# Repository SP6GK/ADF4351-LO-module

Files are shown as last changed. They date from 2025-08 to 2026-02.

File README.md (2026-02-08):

# High Quality RF Local Oscillator Module (ADF4351)

## Overview

This open-source PCB module is designed as a **drop in solution** for any project that requires a **high quality RF continuous wave signal** with at least **16 dBm output power**.  

I present more details on my website: [www.sp6gk.com](https://www.sp6gk.com/).

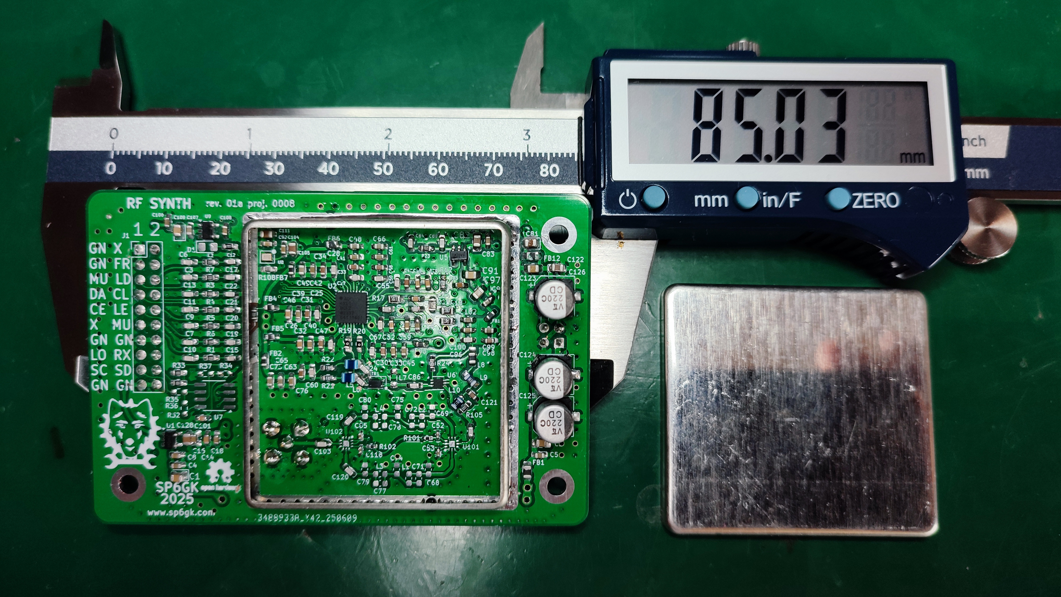
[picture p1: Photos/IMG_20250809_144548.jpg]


The design emphasizes:

- Output power (16–20 dBm depending on frequency)
- Low phase noise
- Minimal harmonics
- Easy integration into custom designs

Originally developed for the **Presto HF to QO-100 transverter project**, this module can be used in a wide variety of RF applications.

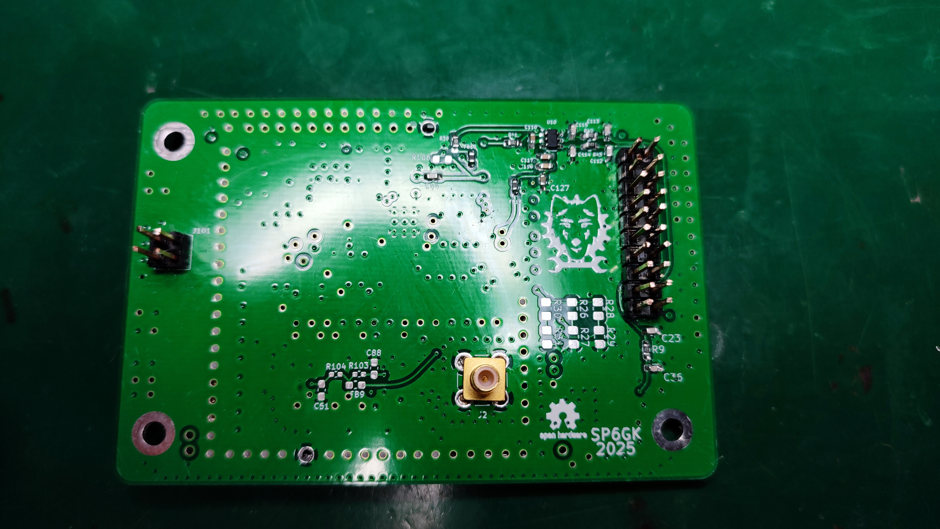
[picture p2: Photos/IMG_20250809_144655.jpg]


---

## Features & Specifications

| Parameter | Value |
|---|---|
| **Optimal Frequency Range** | 400 MHz – 800 MHz (tunable for other ranges) or 1.5-2.1 GHz |
| **Output Power** | 20 dBm (50 Ω load) within optimal range |
| **Power Across Wide Range** | >17 dBm from 100 MHz to 2.4 GHz |
| **Phase Noise @ 400 MHz CW** | -89 dBc/Hz @ 100 Hz offset<br>-97 dBc/Hz @ 10 kHz offset |
| **Reference** | onboard 48 MHz 0.5 ppm VCTCXO + 12-bit DAC digital tuning (or external reference) |
| **Filtering** | Two selectable low-pass filters |
| **PLL Chipset** | Fractional-N PLL (Analog Devices ADF4351) |
| **Dimensions** | 85 × 57 mm |
| **Supply Voltage** | 3.6 V recommended (5.5 V absolute maximum) for logic, 5.3 V for PA stage (5.5 V absolute maximum) |
| **Current Consumption** | < 250 mA (can be reduced by disabling output) |
| **Calibration Storage** | On-board EEPROM |
| **Interface** | SPI (programming PLL) + 3.3 V input pins for switching filters, PA enable etc... |

---

## Applications

- Test and Measurement Equipment
- VHF/UHF Communication Systems
- Amateur Radio
- Backhaul network

---

## Current revisions:
- 400 to 800 MHz rev 01a (tested and presented in the measurements)
- 400 to 800 MHz rev 01b (adds triplexer before amplifier to minimize reflections)
- 1.5-2.1 GHz rev 01a (tuned for higher frequency, includes triplexer and microstrip LPF)

## Performance Measurements

Testing was performed using a **Keysight CXA Spectrum Analyzer (N9000B)** with the **phase noise measurement** option.

**100 MHz**  
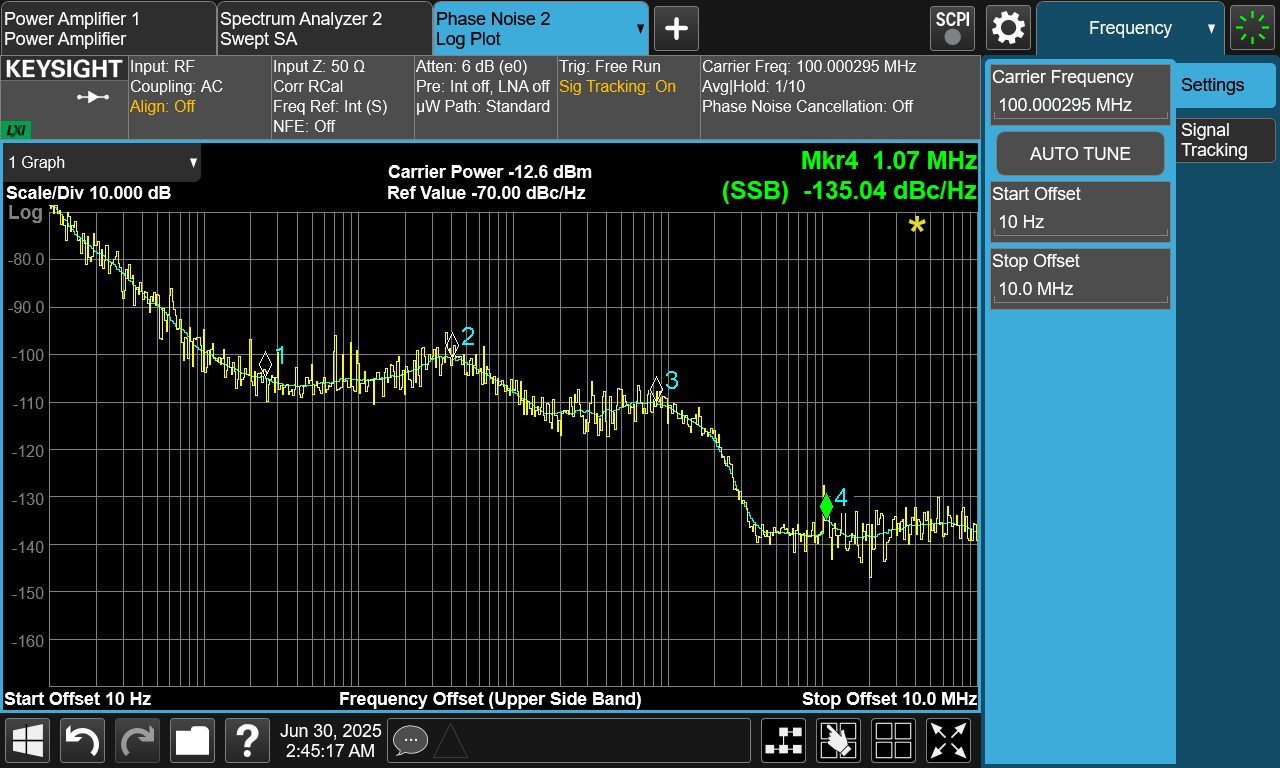
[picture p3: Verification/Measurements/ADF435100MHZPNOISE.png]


**400 MHz**  
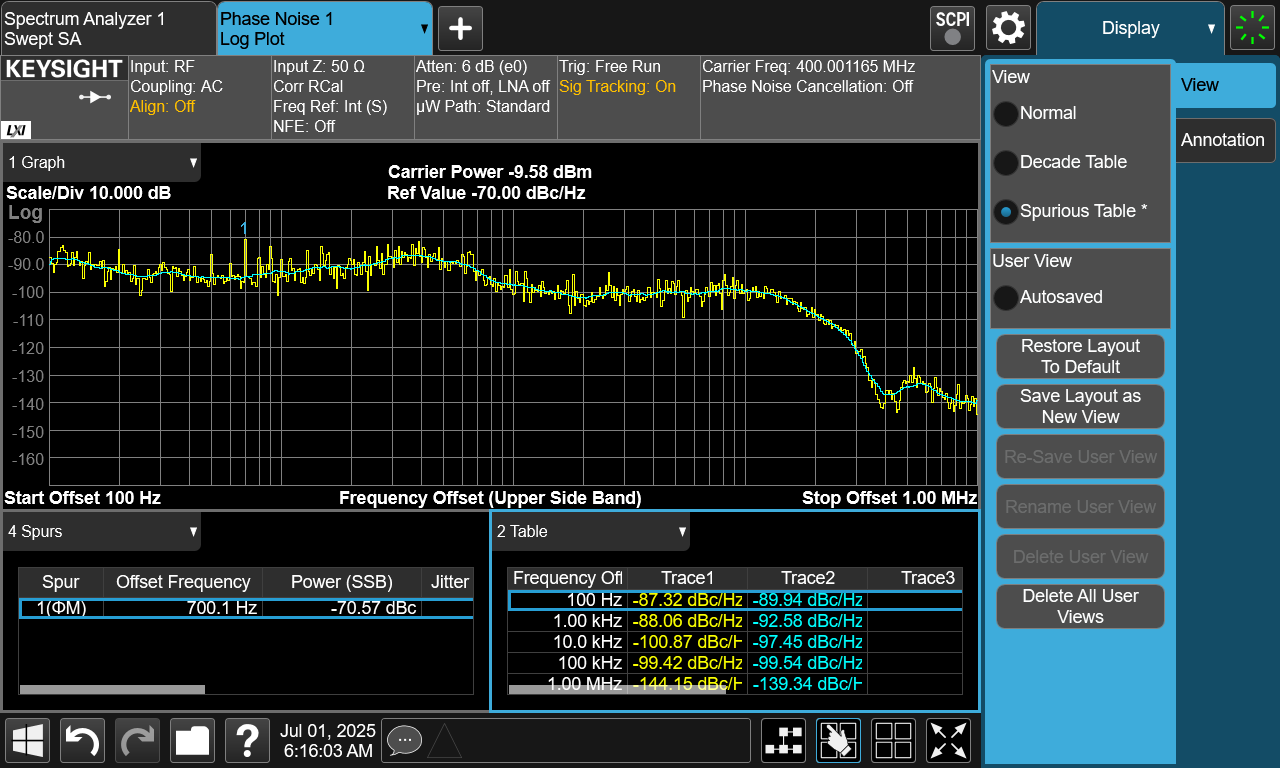
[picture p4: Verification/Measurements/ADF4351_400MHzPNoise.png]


**1.2 GHz**  
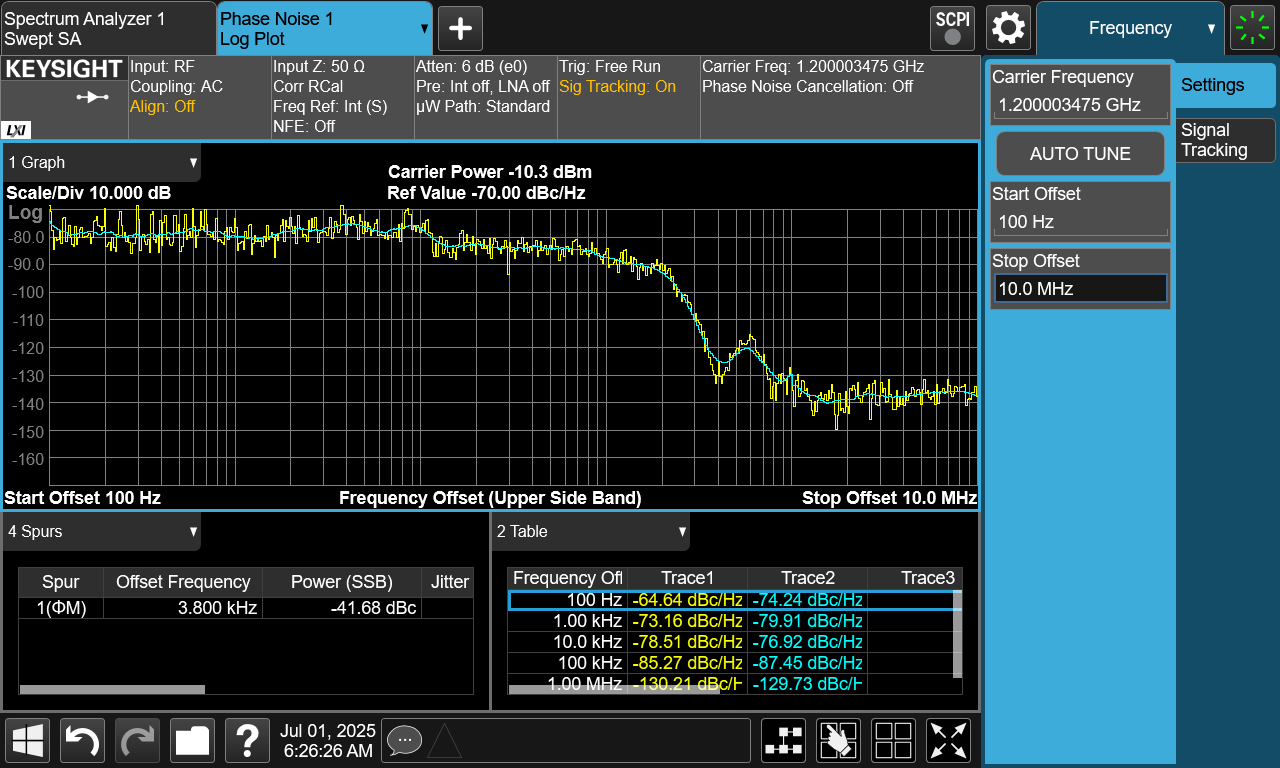
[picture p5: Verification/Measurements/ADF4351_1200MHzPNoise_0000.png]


---

### Harmonics & Output Spectra

**100 MHz CW (50 MHz span)**  
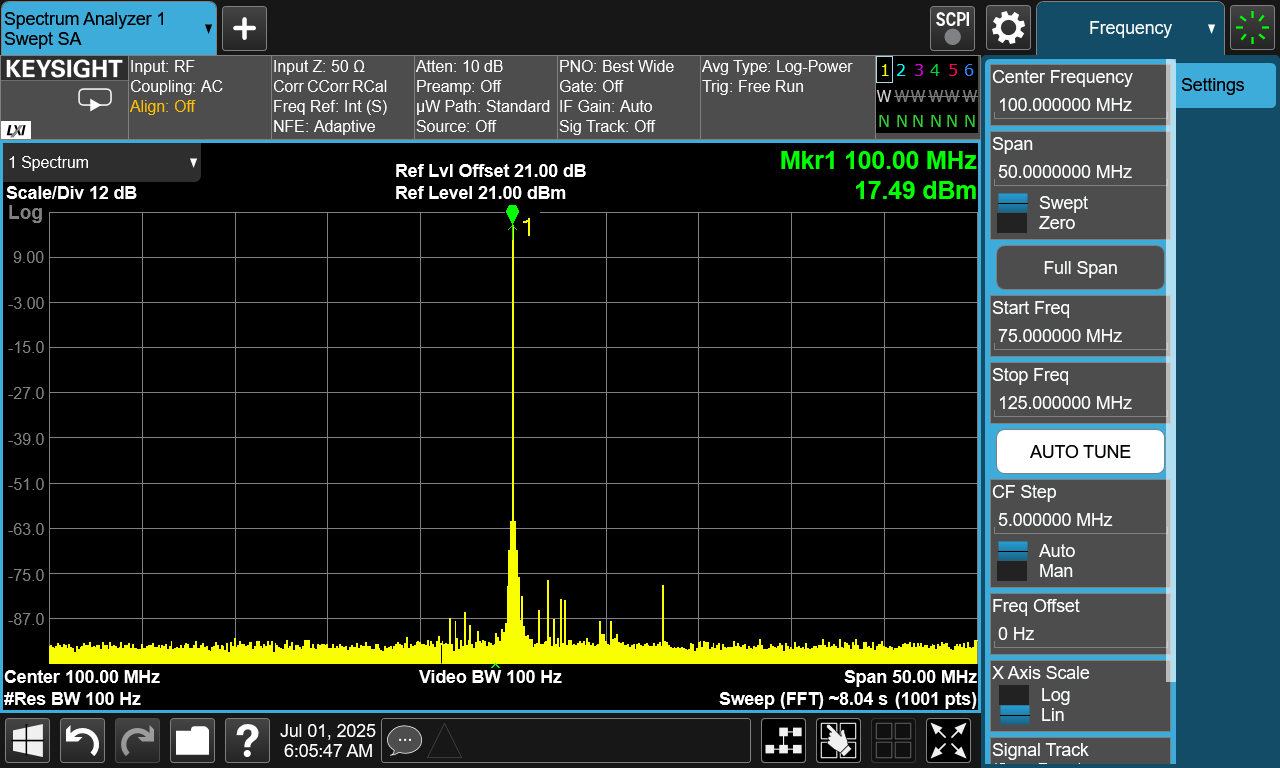
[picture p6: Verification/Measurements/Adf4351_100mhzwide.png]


**400 MHz CW (10 MHz span)**  
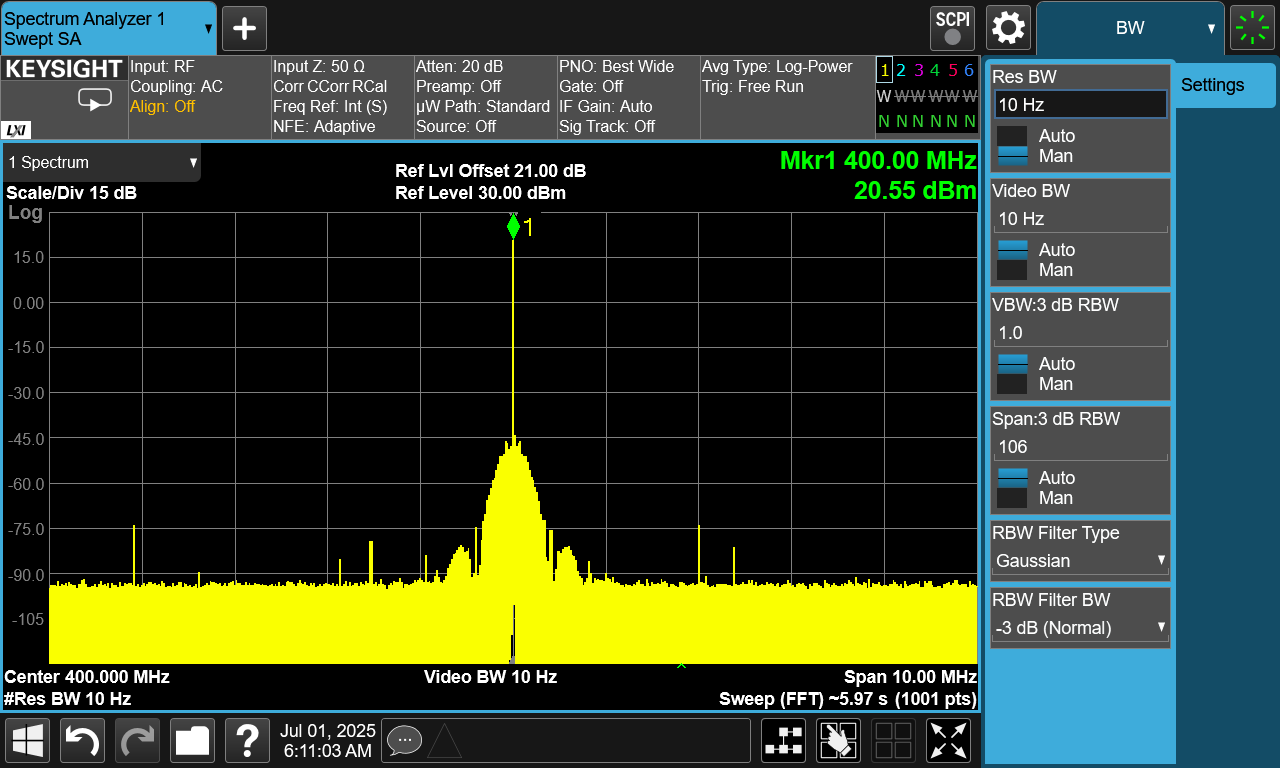
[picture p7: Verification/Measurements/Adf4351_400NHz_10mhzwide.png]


---
Module was tested with STM32F407 discovery board, using driver written by [KB3GTN](https://github.com/kb3gtn/STM32_ADF4351).

---
### What's next?

I intended to use this module for driving a passive RF mixer, however since then I have learned that those work better with square wave LO with lower amplitude.

Currently I am working on revision of this board with LMX2572LP.
I have found this IC to be easier to program while offering better performance especially in terms of spurious emissions.

---

## Repository Contents
- **/ECAD** (Kicad Project, simulations)
- **/Fabrication** (Gerbers)
- **/Verification** (Measurements)
- **/Documents** (BOM)
- **/Photos** (photos of assembled PCB)

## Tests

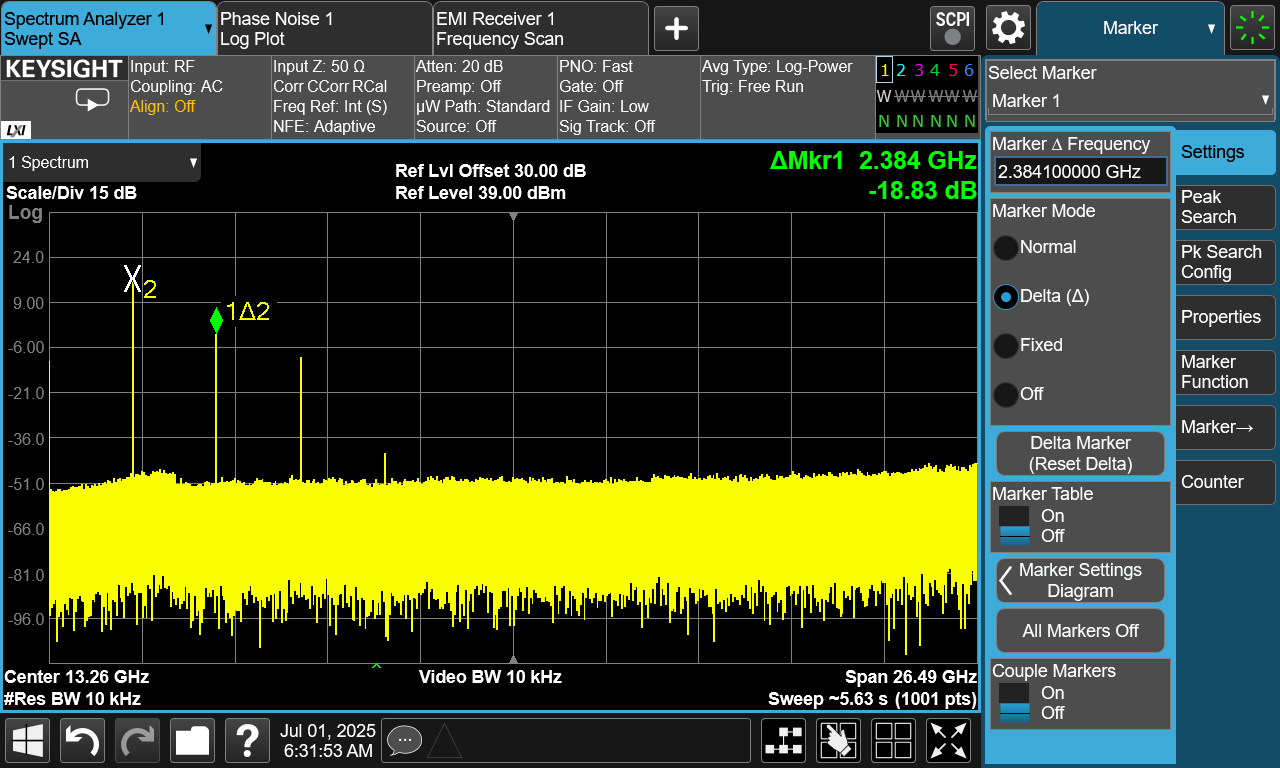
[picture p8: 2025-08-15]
Verification/Measurements/Adf4351_2400MHz_harmonics.png

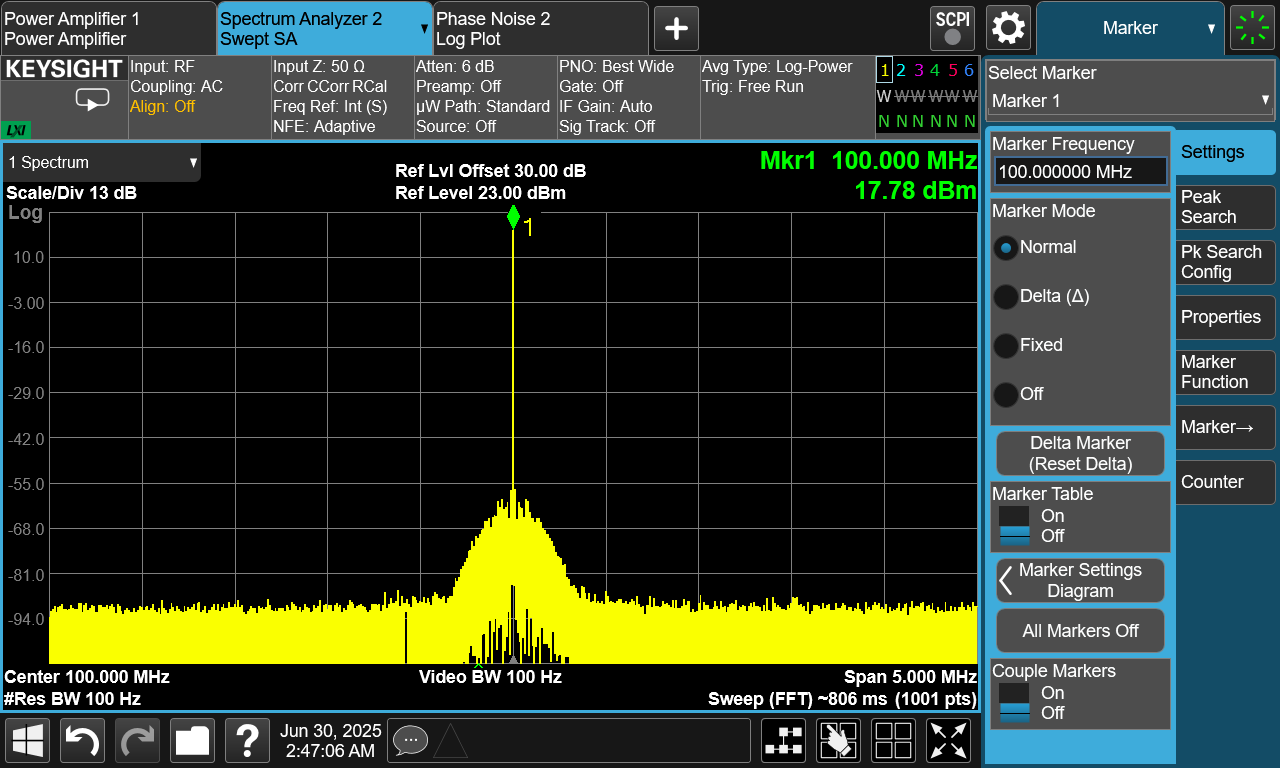
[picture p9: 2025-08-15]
Verification/Measurements/ADF435100MHZPNOISE_0000.png

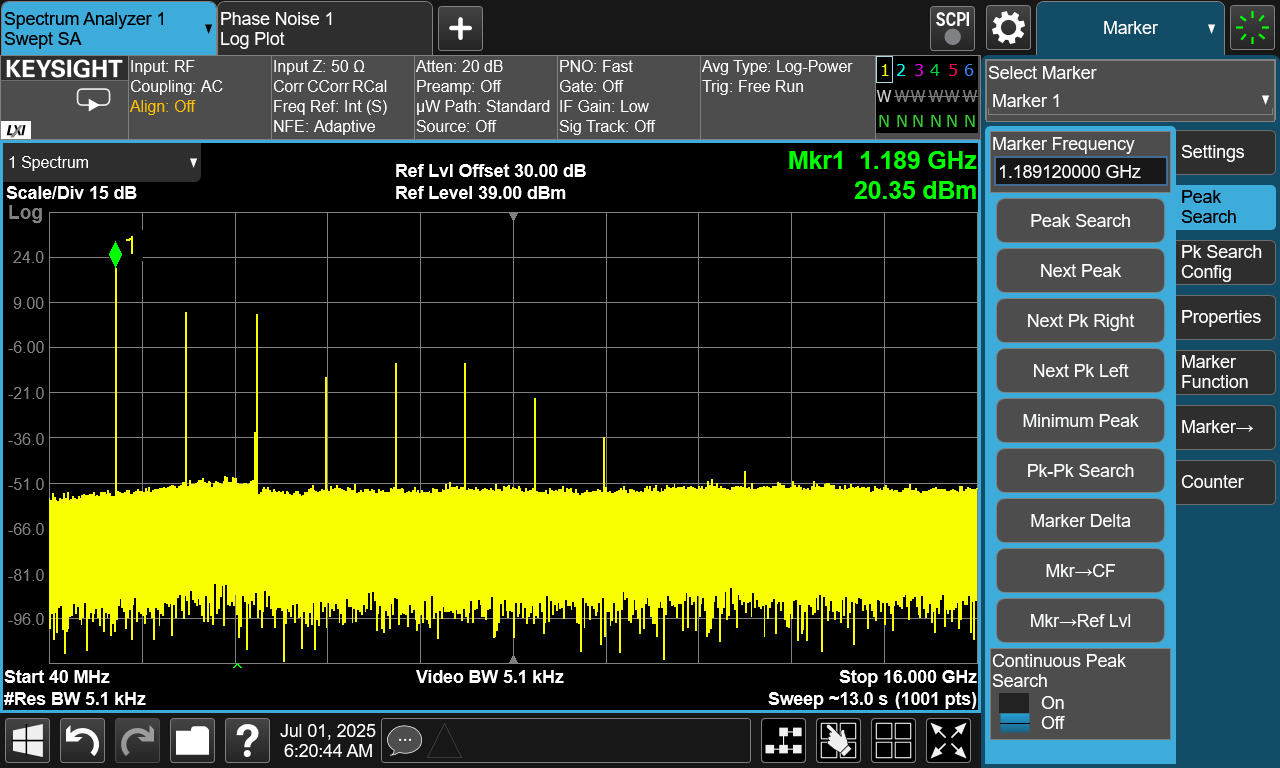
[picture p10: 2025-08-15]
Verification/Measurements/Adf4351_1200MHz_Harmonics_0000.png

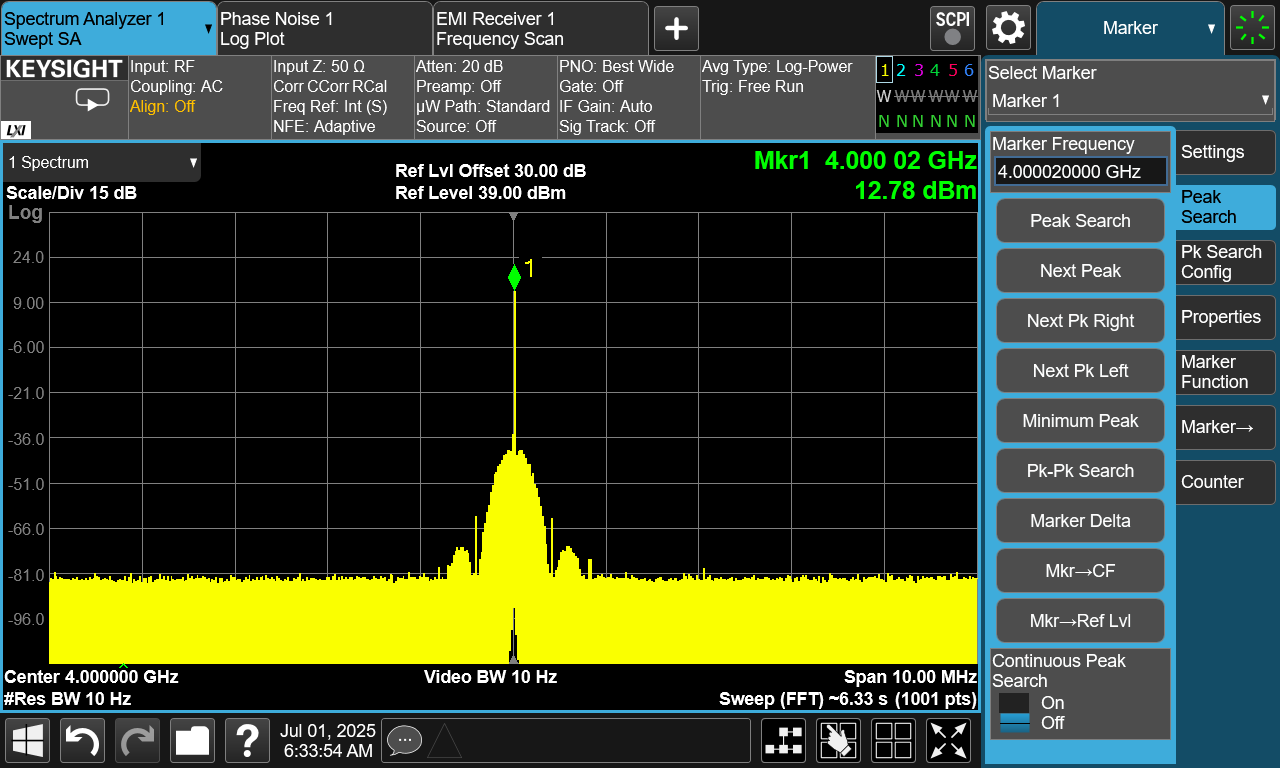
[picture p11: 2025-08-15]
Verification/Measurements/Adf4351_4000MHz_narrow_0000.png

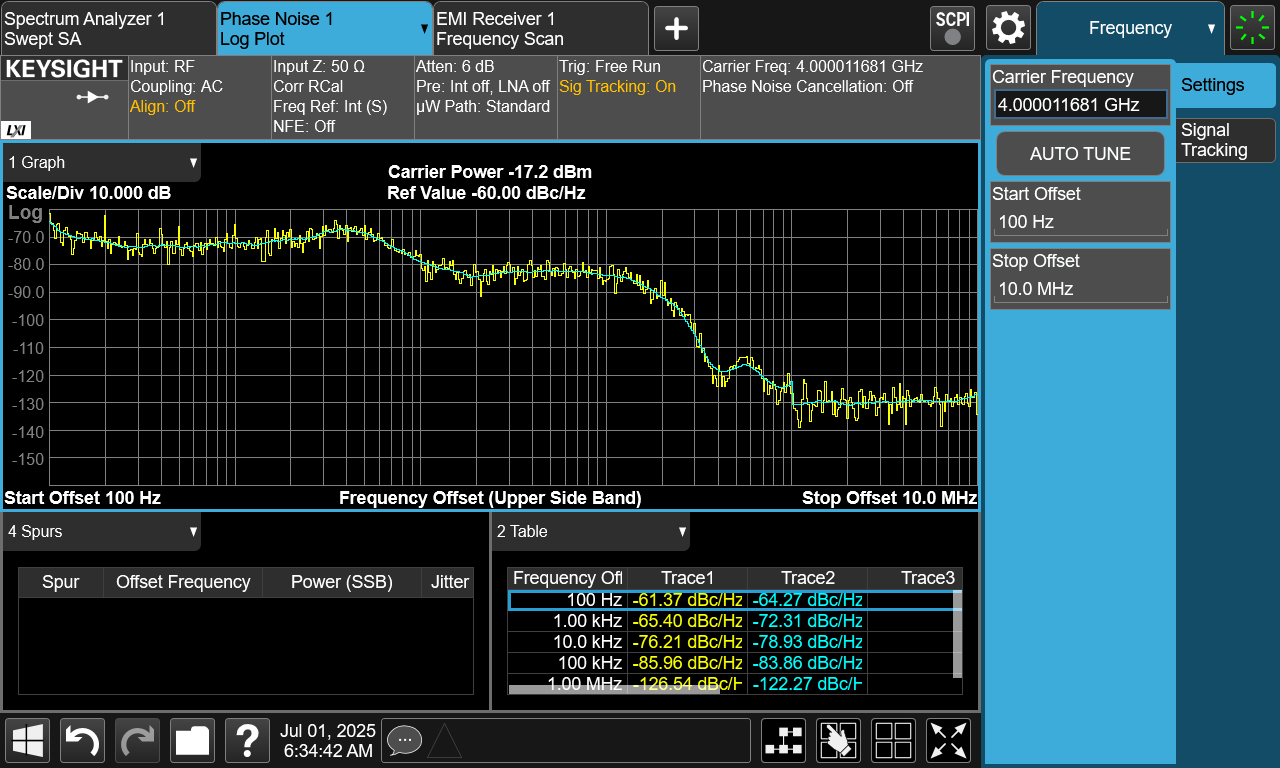
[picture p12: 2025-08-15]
Verification/Measurements/ADF4351_4000MHz_Pnoise.png

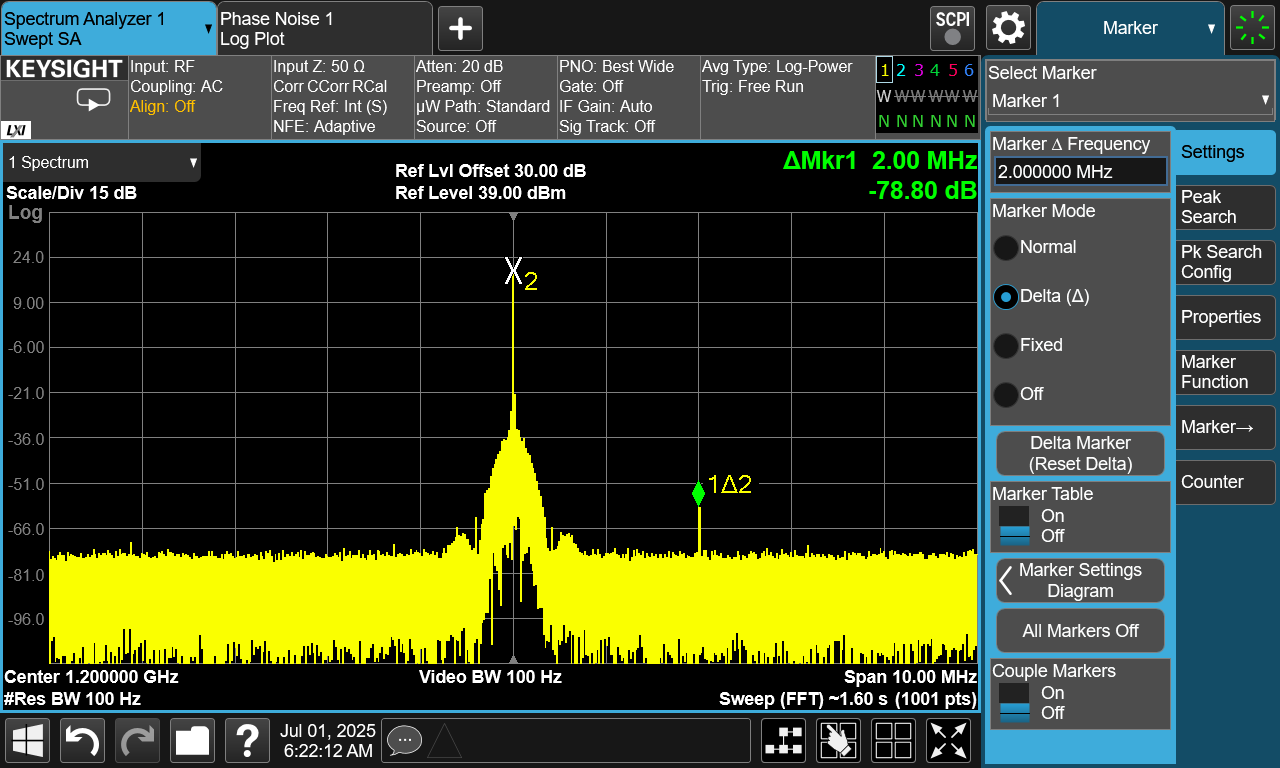
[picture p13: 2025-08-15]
Verification/Measurements/Adf4351_1200MHz_narrow.png

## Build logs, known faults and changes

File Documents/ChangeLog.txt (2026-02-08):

400MHz-800MHz_rev01a initial variant
400MHz-800MHz_rev01b:
    -Added triplexer before amplifier (uses low band)
    -Moved CE resistor to the bottom side so that it is not on the exposed F mask right next to the shield

2GHz_rev01a
    -Adapted to other frequency range:
        -Changed Balun, coupling capacitor, removed two bands and replaced them with one microstrip LPF.
    -Added triplexer before amplifier (uses mid band)
    -Moved CE resistor to the bottom side so that it is not on the exposed F mask right next to the shield

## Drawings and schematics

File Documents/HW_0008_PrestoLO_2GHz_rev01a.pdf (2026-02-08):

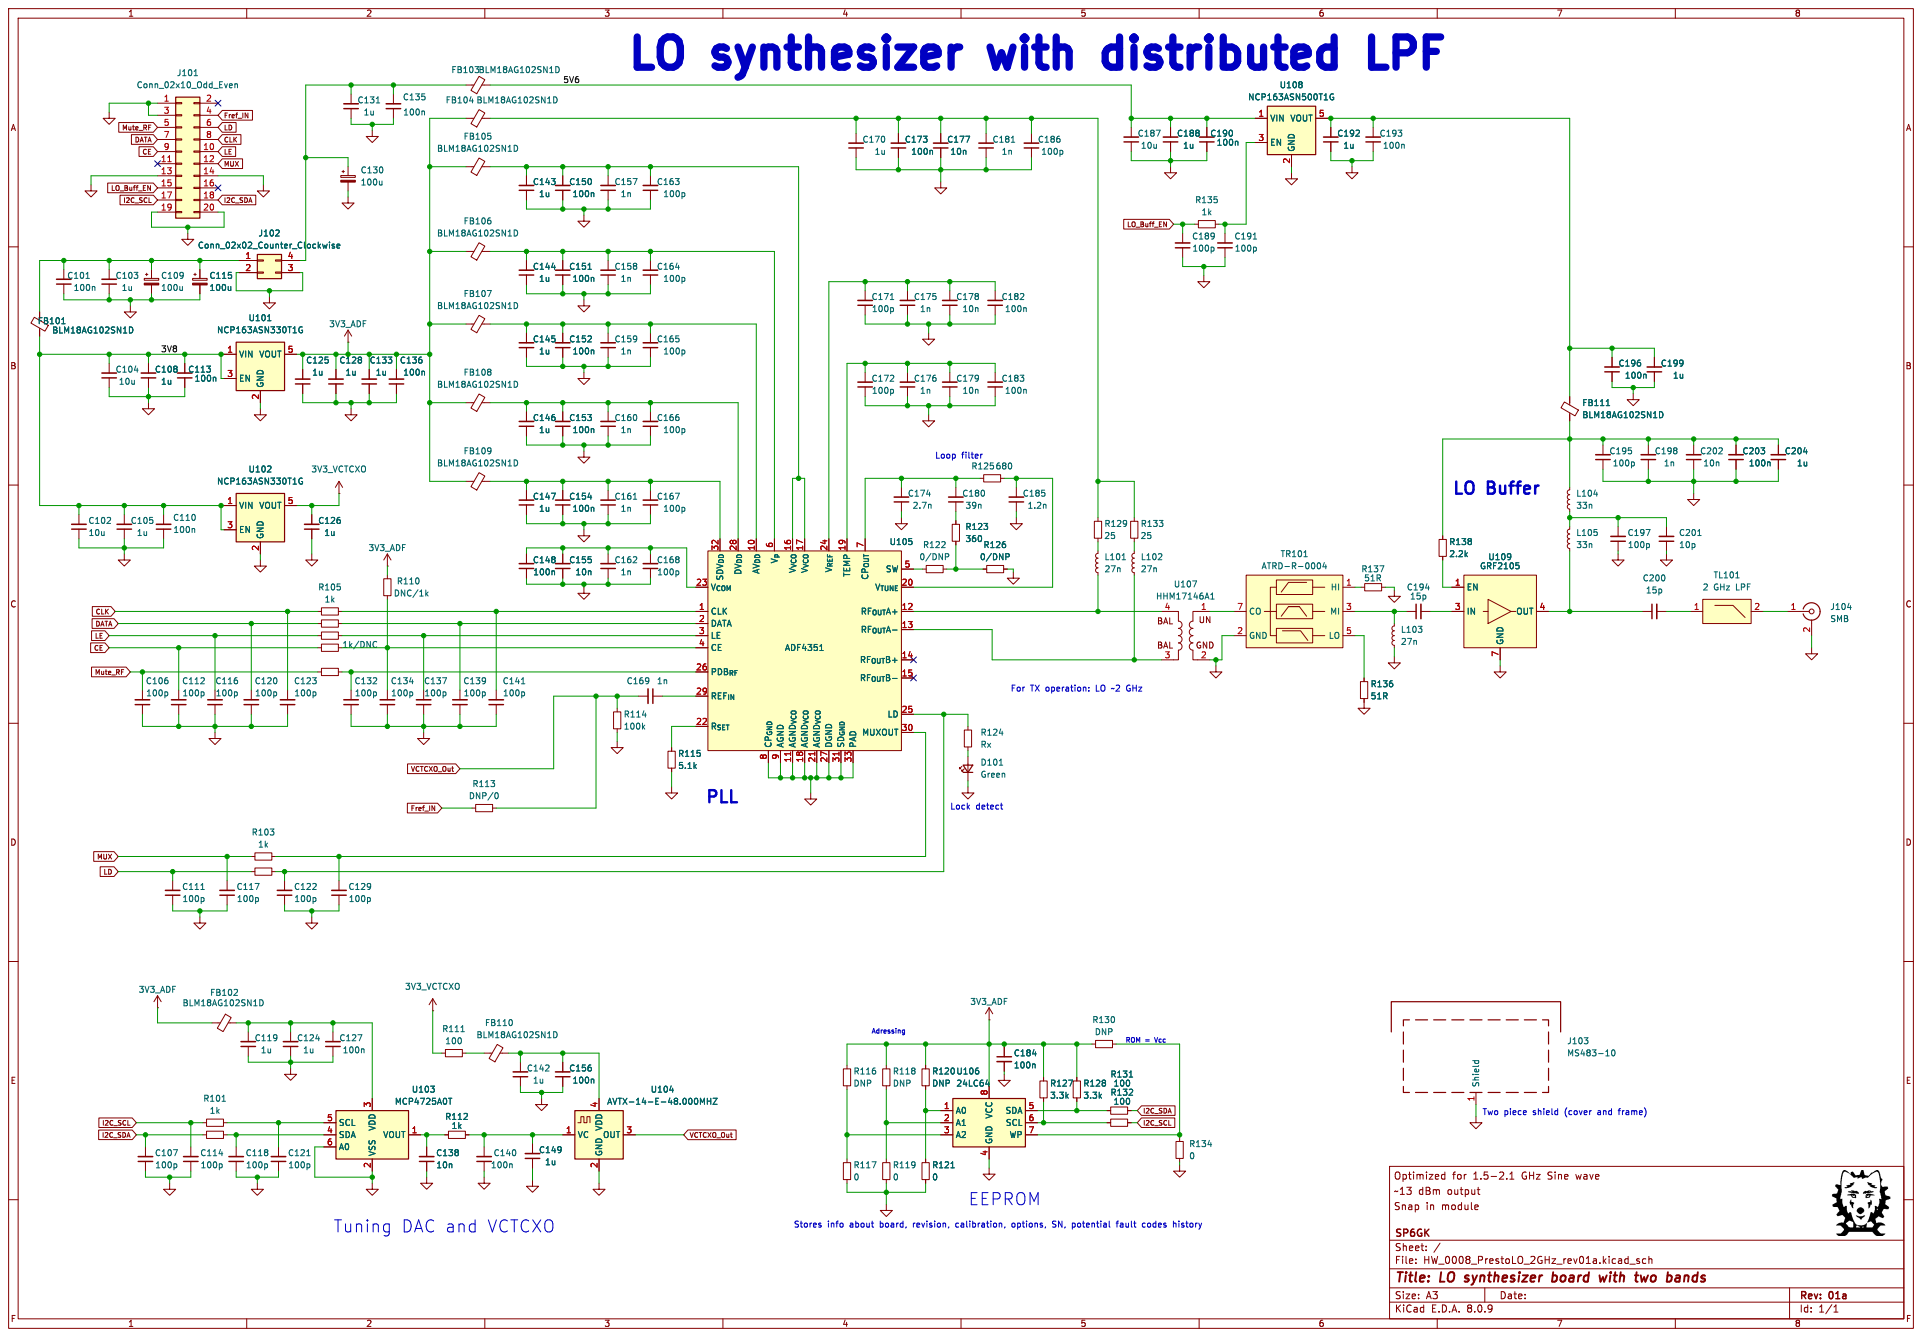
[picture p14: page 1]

4 SDA 5 SCL 6 WP 7 VCC

Id: 1/1 Title: LO synthesizer board with two bands

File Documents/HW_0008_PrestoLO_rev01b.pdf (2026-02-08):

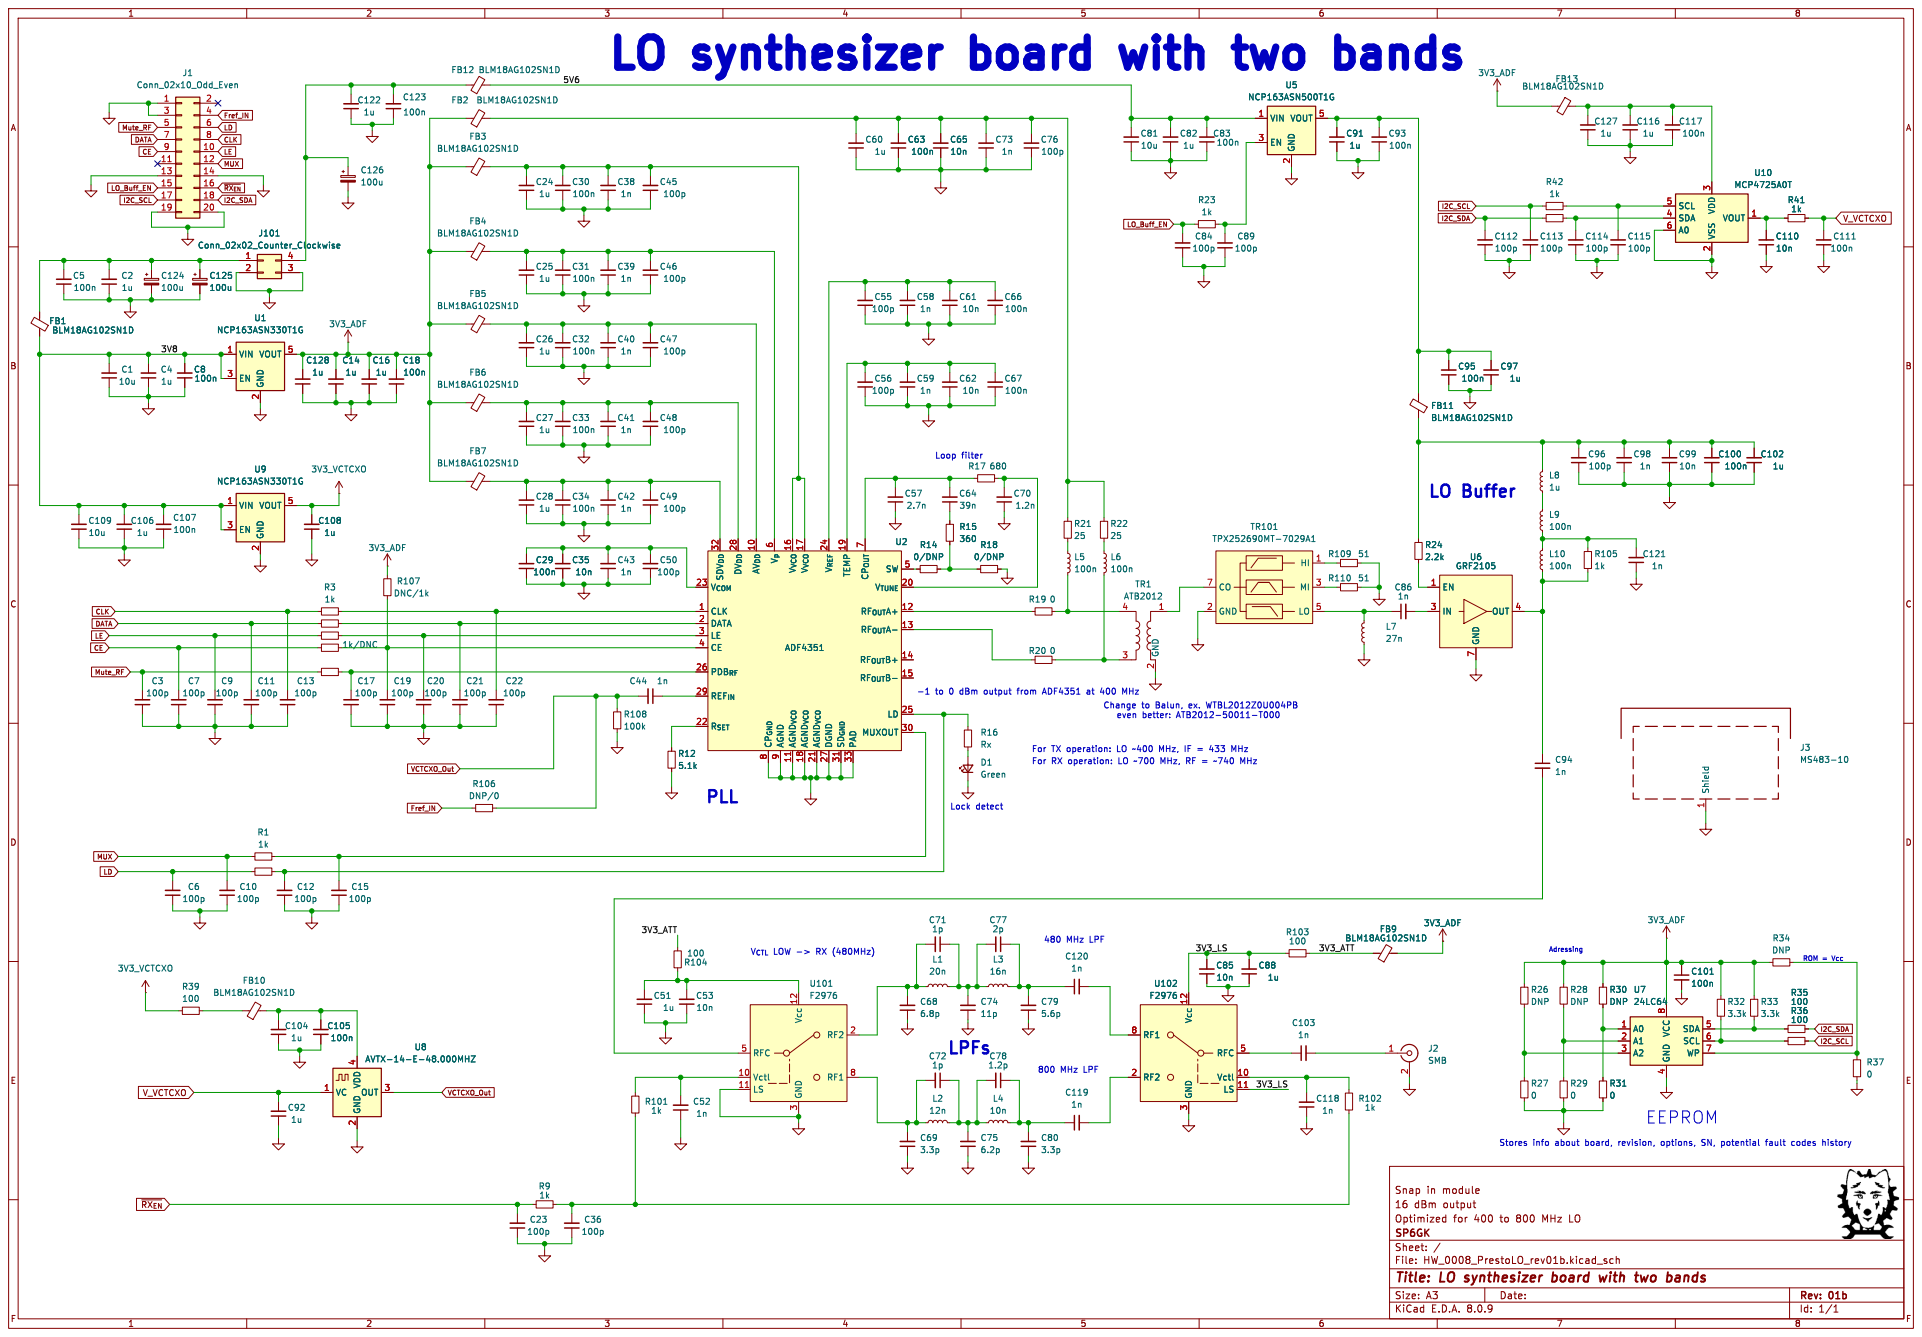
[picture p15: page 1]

Change to Balun, ex. WTBL2012Z0U004PB
even better: ATB2012-50011-T000

Id: 1/1 Title: LO synthesizer board with two bands

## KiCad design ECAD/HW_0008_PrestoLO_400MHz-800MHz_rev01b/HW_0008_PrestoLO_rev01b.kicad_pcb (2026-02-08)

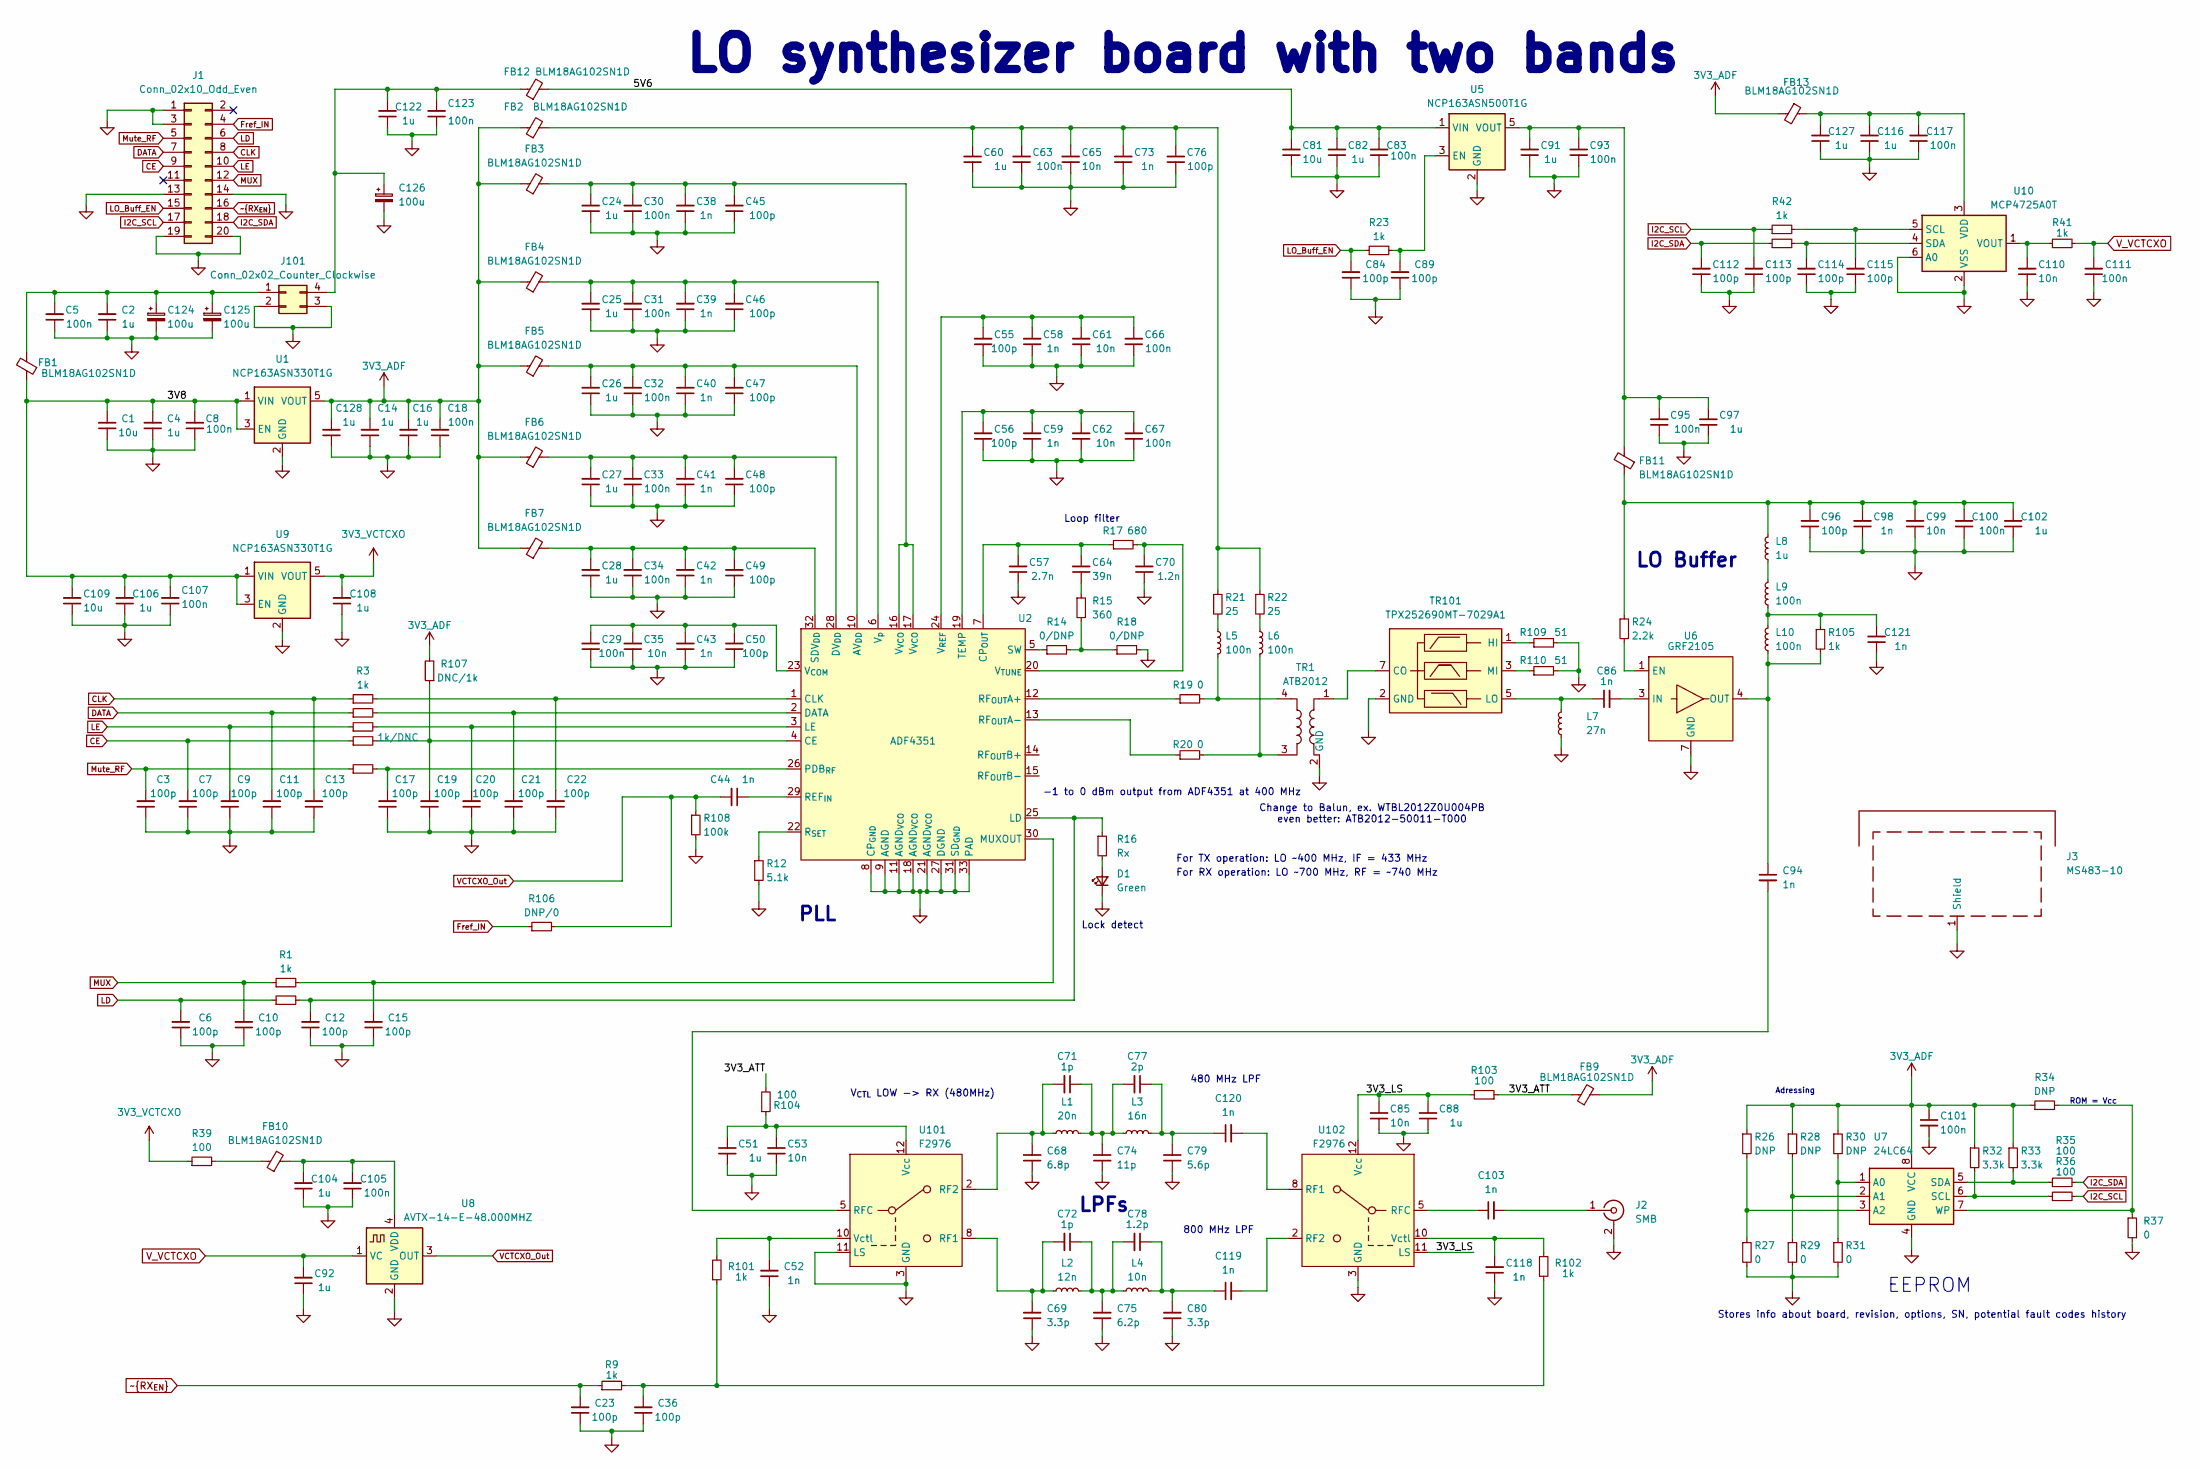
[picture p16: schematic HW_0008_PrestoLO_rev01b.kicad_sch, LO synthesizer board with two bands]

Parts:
C1, C81, C109: 10u; LED_0805_2012Metric
C2, C82, C91, C97, C122: 1u; C_0805_2012Metric_Pad1.18x1.45mm_HandSolder
C3, C6, C7, C9, C10, C11, C12, C13, C15, C17, C19, C20, C21, C22, C23, C36, C45, C46, C47, C48, C49, C50, C55, C56, C76, C84, C89, C96, C112, C113, C114, C115: 100p; C_0603_1608Metric_Pad1.08x0.95mm_HandSolder
C4, C14, C16, C24, C25, C26, C27, C28, C51, C60, C88, C92, C102, C104, C106, C108, C116, C127, C128: 1u; C_0603_1608Metric_Pad1.08x0.95mm_HandSolder
C5, C8, C18, C29, C30, C31, C32, C33, C34, C63, C66, C67, C83, C93, C95, C100, C101, C105, C107, C111, C117: 100n; C_0603_1608Metric_Pad1.08x0.95mm_HandSolder
C35, C61, C62, C65, C99, C110: 10n; C_0603_1608Metric_Pad1.08x0.95mm_HandSolder
C38, C39, C40, C41, C42, C43, C44, C58, C59, C73, C86, C94, C98, C103, C119, C120, C121: 1n; C_0603_1608Metric_Pad1.08x0.95mm_HandSolder
C52, C118: 1n; C_0402_1005Metric_Pad0.74x0.62mm_HandSolder
C53, C85: 10n; C_0402_1005Metric_Pad0.74x0.62mm_HandSolder
C57: 2.7n; C_0603_1608Metric_Pad1.08x0.95mm_HandSolder
C64: 39n; C_0603_1608Metric_Pad1.08x0.95mm_HandSolder
C68: 6.8p; C_0603_1608Metric
C69, C80: 3.3p; C_0603_1608Metric
C70: 1.2n; C_0603_1608Metric_Pad1.08x0.95mm_HandSolder
C71, C72: 1p; C_0603_1608Metric
C74: 11p; C_0603_1608Metric
C75: 6.2p; C_0603_1608Metric
C77: 2p; C_0603_1608Metric
C78: 1.2p; C_0603_1608Metric
C79: 5.6p; C_0603_1608Metric
C123: 100n; C_0805_2012Metric_Pad1.18x1.45mm_HandSolder
C124, C125, C126: 100u; CP_Elec_6.3x5.8
D1: Green; D_0805_2012Metric_Pad1.15x1.40mm_HandSolder
FB1: BLM18AG102SN1D; L_0805_2012Metric_Pad1.15x1.40mm_HandSolder
FB2, FB3, FB4, FB5, FB6, FB7, FB9, FB10, FB11, FB13: BLM18AG102SN1D; L_0603_1608Metric_Pad1.05x0.95mm_HandSolder
FB12: BLM18AG102SN1D; L_0805_2012Metric_Pad1.05x1.20mm_HandSolder
J1: Conn_02x10_Odd_Even; PinHeader_2x10_P2.54mm_Vertical
J2: SMB; SMB_Jack_Vertical
J3: MS483-10; MS4830-10
J101: Conn_02x02_Counter_Clockwise; PinHeader_2x02_P2.54mm_Vertical
L1: 20n; L_0603_1608Metric
L2: 12n; L_0603_1608Metric
L3: 16n; L_0603_1608Metric
L4: 10n; L_0603_1608Metric
L5, L6: 100n; L_0805_2012Metric_Pad1.15x1.40mm_HandSolder
L7: 27n; L_0805_2012Metric_Pad1.05x1.20mm_HandSolder
L8: 1u; L_0805_2012Metric_Pad1.05x1.20mm_HandSolder
L9: 100n; L_0805_2012Metric_Pad1.05x1.20mm_HandSolder
L10: 100n; L_0603_1608Metric_Pad1.05x0.95mm_HandSolder
R1, R2, R3, R4, R5, R7, R9, R23, R41, R42, R43, R105: 1k; R_0603_1608Metric_Pad0.98x0.95mm_HandSolder
R6: 1k/DNC; R_0603_1608Metric_Pad0.98x0.95mm_HandSolder
R12: 5.1k; R_0603_1608Metric_Pad0.98x0.95mm_HandSolder
R14, R18: 0/DNP; R_0603_1608Metric_Pad0.98x0.95mm_HandSolder
R15: 360; R_0603_1608Metric_Pad0.98x0.95mm_HandSolder
R16: Rx; R_0603_1608Metric_Pad0.98x0.95mm_HandSolder
R17: 680; R_0603_1608Metric_Pad0.98x0.95mm_HandSolder
R19, R20, R37: 0; R_0603_1608Metric_Pad0.98x0.95mm_HandSolder
R21, R22: 25; R_0603_1608Metric_Pad0.98x0.95mm_HandSolder
R24: 2.2k; R_0603_1608Metric_Pad0.98x0.95mm_HandSolder
R26, R28, R30: DNP; R_0805_2012Metric_Pad1.20x1.40mm_HandSolder
R27, R29, R31: 0; R_0805_2012Metric_Pad1.20x1.40mm_HandSolder
R32, R33: 3.3k; R_0603_1608Metric_Pad0.98x0.95mm_HandSolder
R34: DNP; R_0603_1608Metric_Pad0.98x0.95mm_HandSolder
R35, R36, R39: 100; R_0603_1608Metric_Pad0.98x0.95mm_HandSolder
R101, R102: 1k; R_0402_1005Metric_Pad0.72x0.64mm_HandSolder
R103, R104: 100; R_0402_1005Metric_Pad0.72x0.64mm_HandSolder
R106: DNP/0; R_0603_1608Metric_Pad0.98x0.95mm_HandSolder
R107: DNC/1k; R_0603_1608Metric_Pad0.98x0.95mm_HandSolder
R108: 100k; R_0603_1608Metric_Pad0.98x0.95mm_HandSolder
R109, R110: 51; R_0603_1608Metric_Pad0.98x0.95mm_HandSolder
TR1: ATB2012
TR101: TPX252690MT-7029A1; TPX252690MT-7029A
U1, U9: NCP163ASN330T1G; SOT-23-5
U2: ADF4351; LFCSP-32-1EP_5x5mm_P0.5mm_EP3.5x3.5mm_ThermalVias
U5: NCP163ASN500T1G; SOT-23-5
U6: GRF2105; DFN-6-1EP_2x2mm_P0.5mm_EP0.6x1.37mm
U7: 24LC64; SOIC-8_3.9x4.9mm_P1.27mm
U8: AVTX-14-E-48.000MHZ; AbracomAVTX_14
U10: MCP4725A0T; SOT-23-6
U101, U102: F2976

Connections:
3V3_ADF: C14.2, C16.2, C18.2, C101.1, C128.2, FB2.1, FB3.1, FB4.1, FB5.1, FB6.1, FB7.1, FB9.2, FB13.2, R26.1, R28.1, R30.1, R32.1, R33.1, R34.1, R107.2, U1.5 (VOUT), U7.8 (VCC)
3V3_VCTCXO: C108.2, R39.1, U9.5 (VOUT)
/3V3_ATT: FB9.1, R103.1, R104.2
/3V3_LS: C85.2, C88.2, R103.2, U102.11 (LS), U102.12 (Vcc)
/3V8: C1.2, C4.2, C8.2, C106.2, C107.2, C109.2, FB1.1, U1.1 (VIN), U1.3 (EN), U9.1 (VIN), U9.3 (EN)
/5V6: C81.2, C82.2, C83.2, FB12.2, U5.1 (VIN)
CE: C7.2, J1.9, R6.1
CLK: C13.2, J1.8, R3.1
DATA: C11.2, J1.7, R4.1
Fref_IN: J1.4, R106.1
GND: C1.1, C2.1, C3.1, C4.1, C5.1, C6.1, C7.1, C8.1, C9.1, C10.1, C11.1, C12.1, C13.1, C14.1, C15.1, C16.1, C17.1, C18.1, C19.1, C20.1, C21.1, C22.1, C23.1, C24.1, C25.1, C26.1, C27.1, C28.1, C29.1, C30.1, C31.1, C32.1, C33.1, C34.1, C35.1, C36.1, C38.1, C39.1, C40.1, C41.1, C42.1, C43.1, C45.1, C46.1, C47.1, C48.1, C49.1, C50.1, C51.1, C52.1, C53.1, C55.1, C56.1, C57.1, C58.1, C59.1, C60.1, C61.1, C62.1, C63.1, C65.1, C66.1, C67.1, C68.1, C69.1, C70.1, C73.1, C74.1, C75.1, C76.1, C79.1, C80.1, C81.1, C82.1, C83.1, C84.1, C85.1, C88.1, C89.1, C91.1, C92.1, C93.1, C95.1, C96.1, C97.1, C98.1, C99.1, C100.1, C101.2, C102.1, C104.1, C105.1, C106.1, C107.1, C108.1, C109.1, C110.1, C111.1, C112.1, C113.1, C114.1, C115.1, C116.1, C117.1, C118.1, C121.1, C122.1, C123.1, C124.2, C125.2, C126.2, C127.1, C128.1, D1.1 (K), J1.1, J1.3, J1.13, J1.14, J1.19, J1.20, J2.2 (Ext), J3.1 (Shield), J101.2, J101.3, L7.1, R12.2, R18.2, R27.2, R29.2, R31.2, R37.2, R108.2, R109.2, R110.2, TR1.2 (GND), TR101.2 (GND), TR101.4 (GND), TR101.6 (GND), TR101.8 (GND), TR101.9 (GND), U1.2 (GND), U2.8 (CP_{GND}), U2.9 (AGND), U2.11 (AGND_{VCO}), U2.18 (AGND_{VCO}), U2.21 (AGND_{VCO}), U2.27 (DGND), U2.31 (SD_{GND}), U2.33 (PAD), U5.2 (GND), U6.2 (GND), U6.5 (GND), U6.6 (GND), U6.7 (GND), U7.4 (GND), U8.2 (GND), U9.2 (GND), U10.2 (VSS), U10.6 (A0), U101.1 (GND), U101.3 (GND), U101.4 (GND), U101.6 (GND), U101.7 (GND), U101.9 (GND), U101.11 (LS), U101.EP (GND), U102.1 (GND), U102.3 (GND), U102.4 (GND), U102.6 (GND), U102.7 (GND), U102.9 (GND), U102.EP (GND)
I2C_SCL: C113.2, J1.17, R36.2, R42.1
I2C_SDA: C112.2, J1.18, R35.2, R43.1
LD: C6.2, J1.6, R2.1
LE: C9.2, J1.10, R5.1
LO_Buff_EN: C84.2, J1.15, R23.1
MUX: C10.2, J1.12, R1.1
Mute_RF: C3.2, J1.5, R7.1
unnamed: C24.2, C30.2, C38.2, C45.2, FB3.2, U2.16 (V_{VCO}), U2.17 (V_{VCO})
unnamed: C36.2, R9.2, R101.1, R102.1
unnamed: C60.2, C63.2, C65.2, C73.2, C76.2, FB2.2, R21.1, R22.1
unnamed: C64.1, R15.1
unnamed: C71.1, C74.2, C77.2, L1.2, L3.1
unnamed: C72.1, C75.2, C78.2, L2.2, L4.1
unnamed: C96.2, C98.2, C99.2, C100.2, C102.2, FB11.1, L8.2, R24.1
unnamed: C78.1, C80.2, C119.1, L4.2
unnamed: C77.1, C79.2, C120.1, L3.2
unnamed: C121.2, L9.1, L10.2, R105.1
unnamed: D1.2 (A), R16.2
unnamed: FB10.1, R39.2
unnamed: C103.2, J2.1 (In)
unnamed: C2.2, C5.2, C124.1, C125.1, FB1.2, J101.1
unnamed: C122.2, C123.2, C126.1, FB12.1, J101.4
unnamed: L5.1, R21.2
unnamed: L5.2, R19.2, TR1.4
unnamed: L6.1, R22.2
unnamed: L6.2, R20.2, TR1.3
unnamed: L8.1, L9.2
unnamed: R14.2, R15.2, R18.1
unnamed: TR1.1, TR101.7 (CO)
unnamed: R109.1, TR101.1 (HI)
unnamed: C86.1, L7.2, TR101.5 (LO)
unnamed: R110.1, TR101.3 (MI)
unnamed: C26.2, C32.2, C40.2, C47.2, FB5.2, U2.10 (AV_{DD})
unnamed: C19.2, R6.2, R107.1, U2.4 (CE)
unnamed: C22.2, R3.2, U2.1 (CLK)
unnamed: C57.2, C64.2, R17.1, U2.7 (CP_{OUT})
unnamed: C21.2, R4.2, U2.2 (DATA)
unnamed: C27.2, C33.2, C41.2, C48.2, FB6.2, U2.28 (DV_{DD})
unnamed: C12.2, R2.2, R16.1, U2.25 (LD)
unnamed: C20.2, R5.2, U2.3 (LE)
unnamed: C15.2, R1.2, U2.30 (MUXOUT)
unnamed: C17.2, R7.2, U2.26 (PDB_{RF})
unnamed: C44.1, U2.29 (REF_{IN})
unnamed: R19.1, U2.12 (RF_{OUT}A+)
unnamed: R20.1, U2.13 (RF_{OUT}A-)
unnamed: R12.1, U2.22 (R_{SET})
unnamed: C28.2, C34.2, C42.2, C49.2, FB7.2, U2.32 (SDV_{DD})
unnamed: R14.1, U2.5 (SW)
unnamed: C56.2, C59.2, C62.2, C67.2, U2.19 (TEMP)
unnamed: C29.2, C35.2, C43.2, C50.2, U2.23 (V_{COM})
unnamed: C55.2, C58.2, C61.2, C66.2, U2.24 (V_{REF})
unnamed: C70.2, R17.2, U2.20 (V_{TUNE})
unnamed: C25.2, C31.2, C39.2, C46.2, FB4.2, U2.6 (V_{p})
unnamed: C89.2, R23.2, U5.3 (EN)
unnamed: C91.2, C93.2, C95.2, C97.2, FB11.2, U5.5 (VOUT)
unnamed: R24.2, U6.1 (EN)
unnamed: C86.2, U6.3 (IN)
unnamed: C94.1, L10.1, R105.2, U6.4 (OUT)
unnamed: R30.2, R31.1, U7.1 (A0)
unnamed: R28.2, R29.1, U7.2 (A1)
unnamed: R26.2, R27.1, U7.3 (A2)
unnamed: R32.2, R36.1, U7.6 (SCL)
unnamed: R33.2, R35.1, U7.5 (SDA)
unnamed: R34.2, R37.1, U7.7 (WP)
unnamed: C104.2, C105.2, FB10.2, U8.4 (VDD)
unnamed: C115.2, R42.2, U10.5 (SCL)
unnamed: C114.2, R43.2, U10.4 (SDA)
unnamed: C116.2, C117.2, C127.2, FB13.1, U10.3 (VDD)
unnamed: C110.2, R41.1, U10.1 (VOUT)
unnamed: C69.2, C72.2, L2.1, U101.8 (RF1)
unnamed: C68.2, C71.2, L1.1, U101.2 (RF2)
unnamed: C94.2, U101.5 (RFC)
unnamed: C51.2, C53.2, R104.1, U101.12 (Vcc)
unnamed: C52.2, R101.2, U101.10 (Vctl)
unnamed: C120.2, U102.8 (RF1)
unnamed: C119.2, U102.2 (RF2)
unnamed: C103.1, U102.5 (RFC)
unnamed: C118.2, R102.2, U102.10 (Vctl)
VCTCXO_Out: C44.2, R106.2, R108.1, U8.3 (OUT)
V_VCTCXO: C92.2, C111.2, R41.2, U8.1 (VC)
~RX_{EN}: C23.2, J1.16, R9.1

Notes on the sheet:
EEPROM
LPFs
Adressing
-1 to 0 dBm output from ADF4351 at 400 MHz
800 MHz LPF
480 MHz LPF
Lock detect
PLL
For TX operation: LO ~400 MHz, IF = 433 MHz
LO Buffer
Loop filter
LO synthesizer board with two bands
For RX operation: LO ~700 MHz, RF = ~740 MHz
Stores info about board, revision, options, SN, potential fault codes history
Change to Balun, ex. WTBL2012Z0U004PB even better: ATB2012-50011-T000
ROM = Vcc
V_{CTL} LOW -> RX (480MHz)

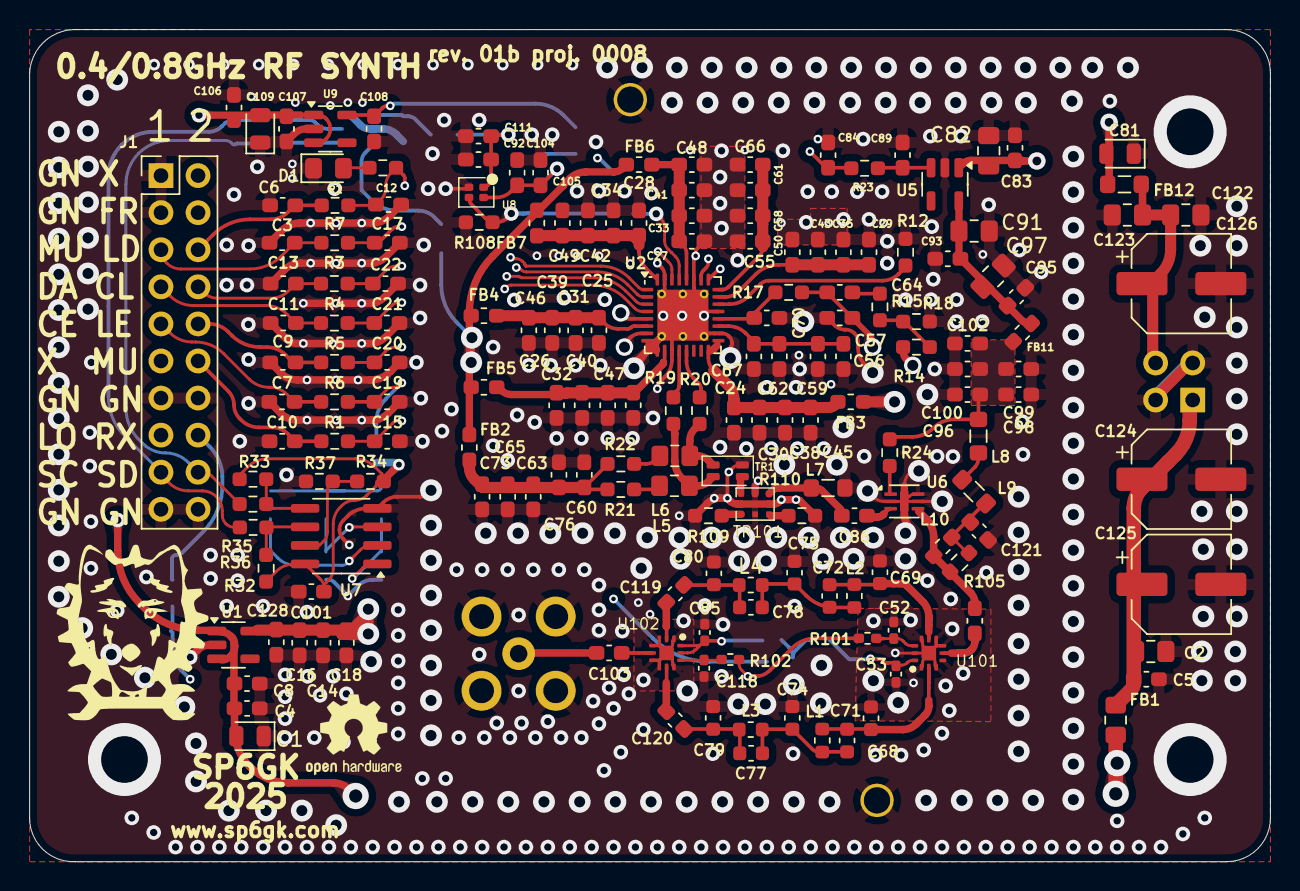
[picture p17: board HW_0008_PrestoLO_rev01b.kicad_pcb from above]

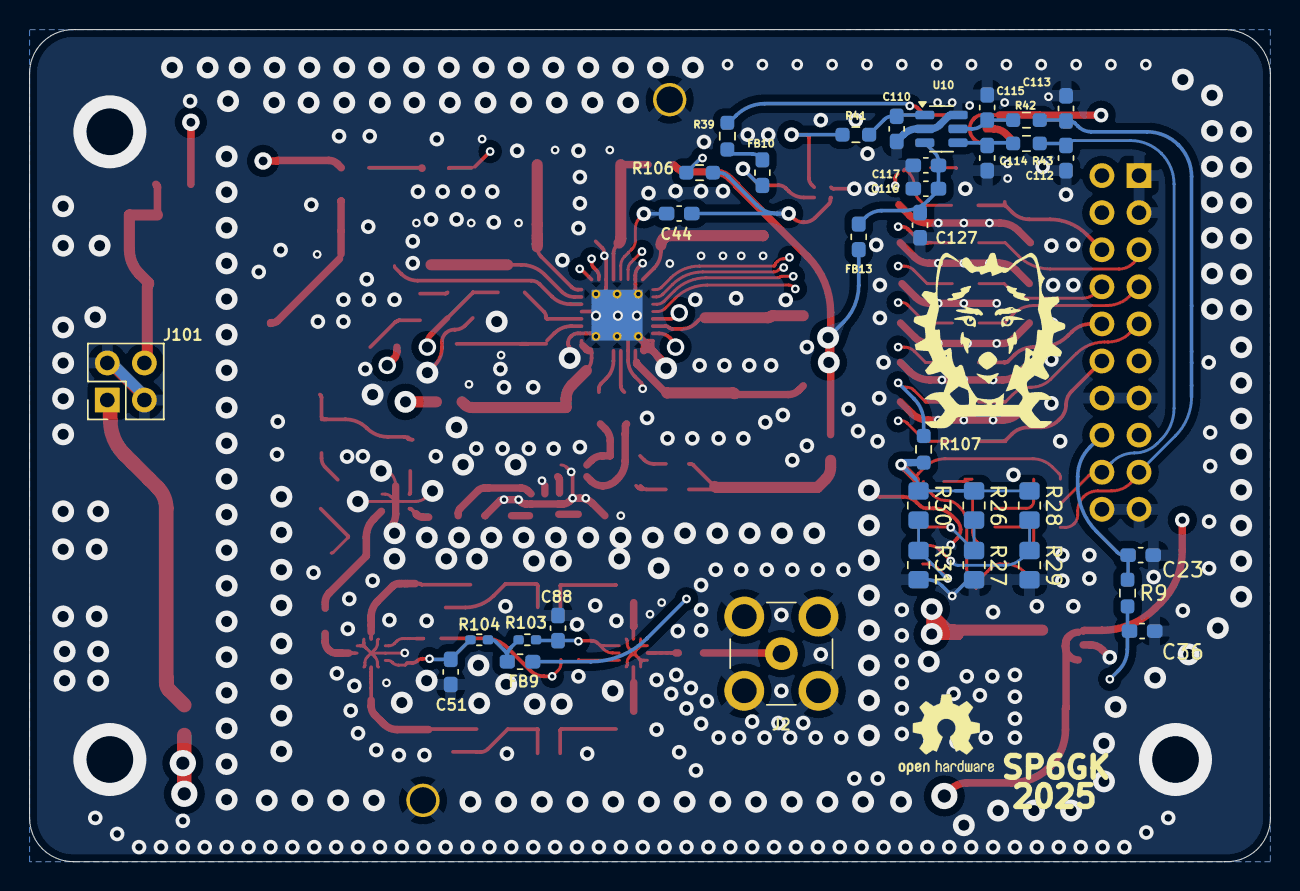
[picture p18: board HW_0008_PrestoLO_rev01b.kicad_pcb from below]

Board: 4 copper layers, 85.0 x 57.0 mm, 209 parts (34 on the bottom side), 92 nets.

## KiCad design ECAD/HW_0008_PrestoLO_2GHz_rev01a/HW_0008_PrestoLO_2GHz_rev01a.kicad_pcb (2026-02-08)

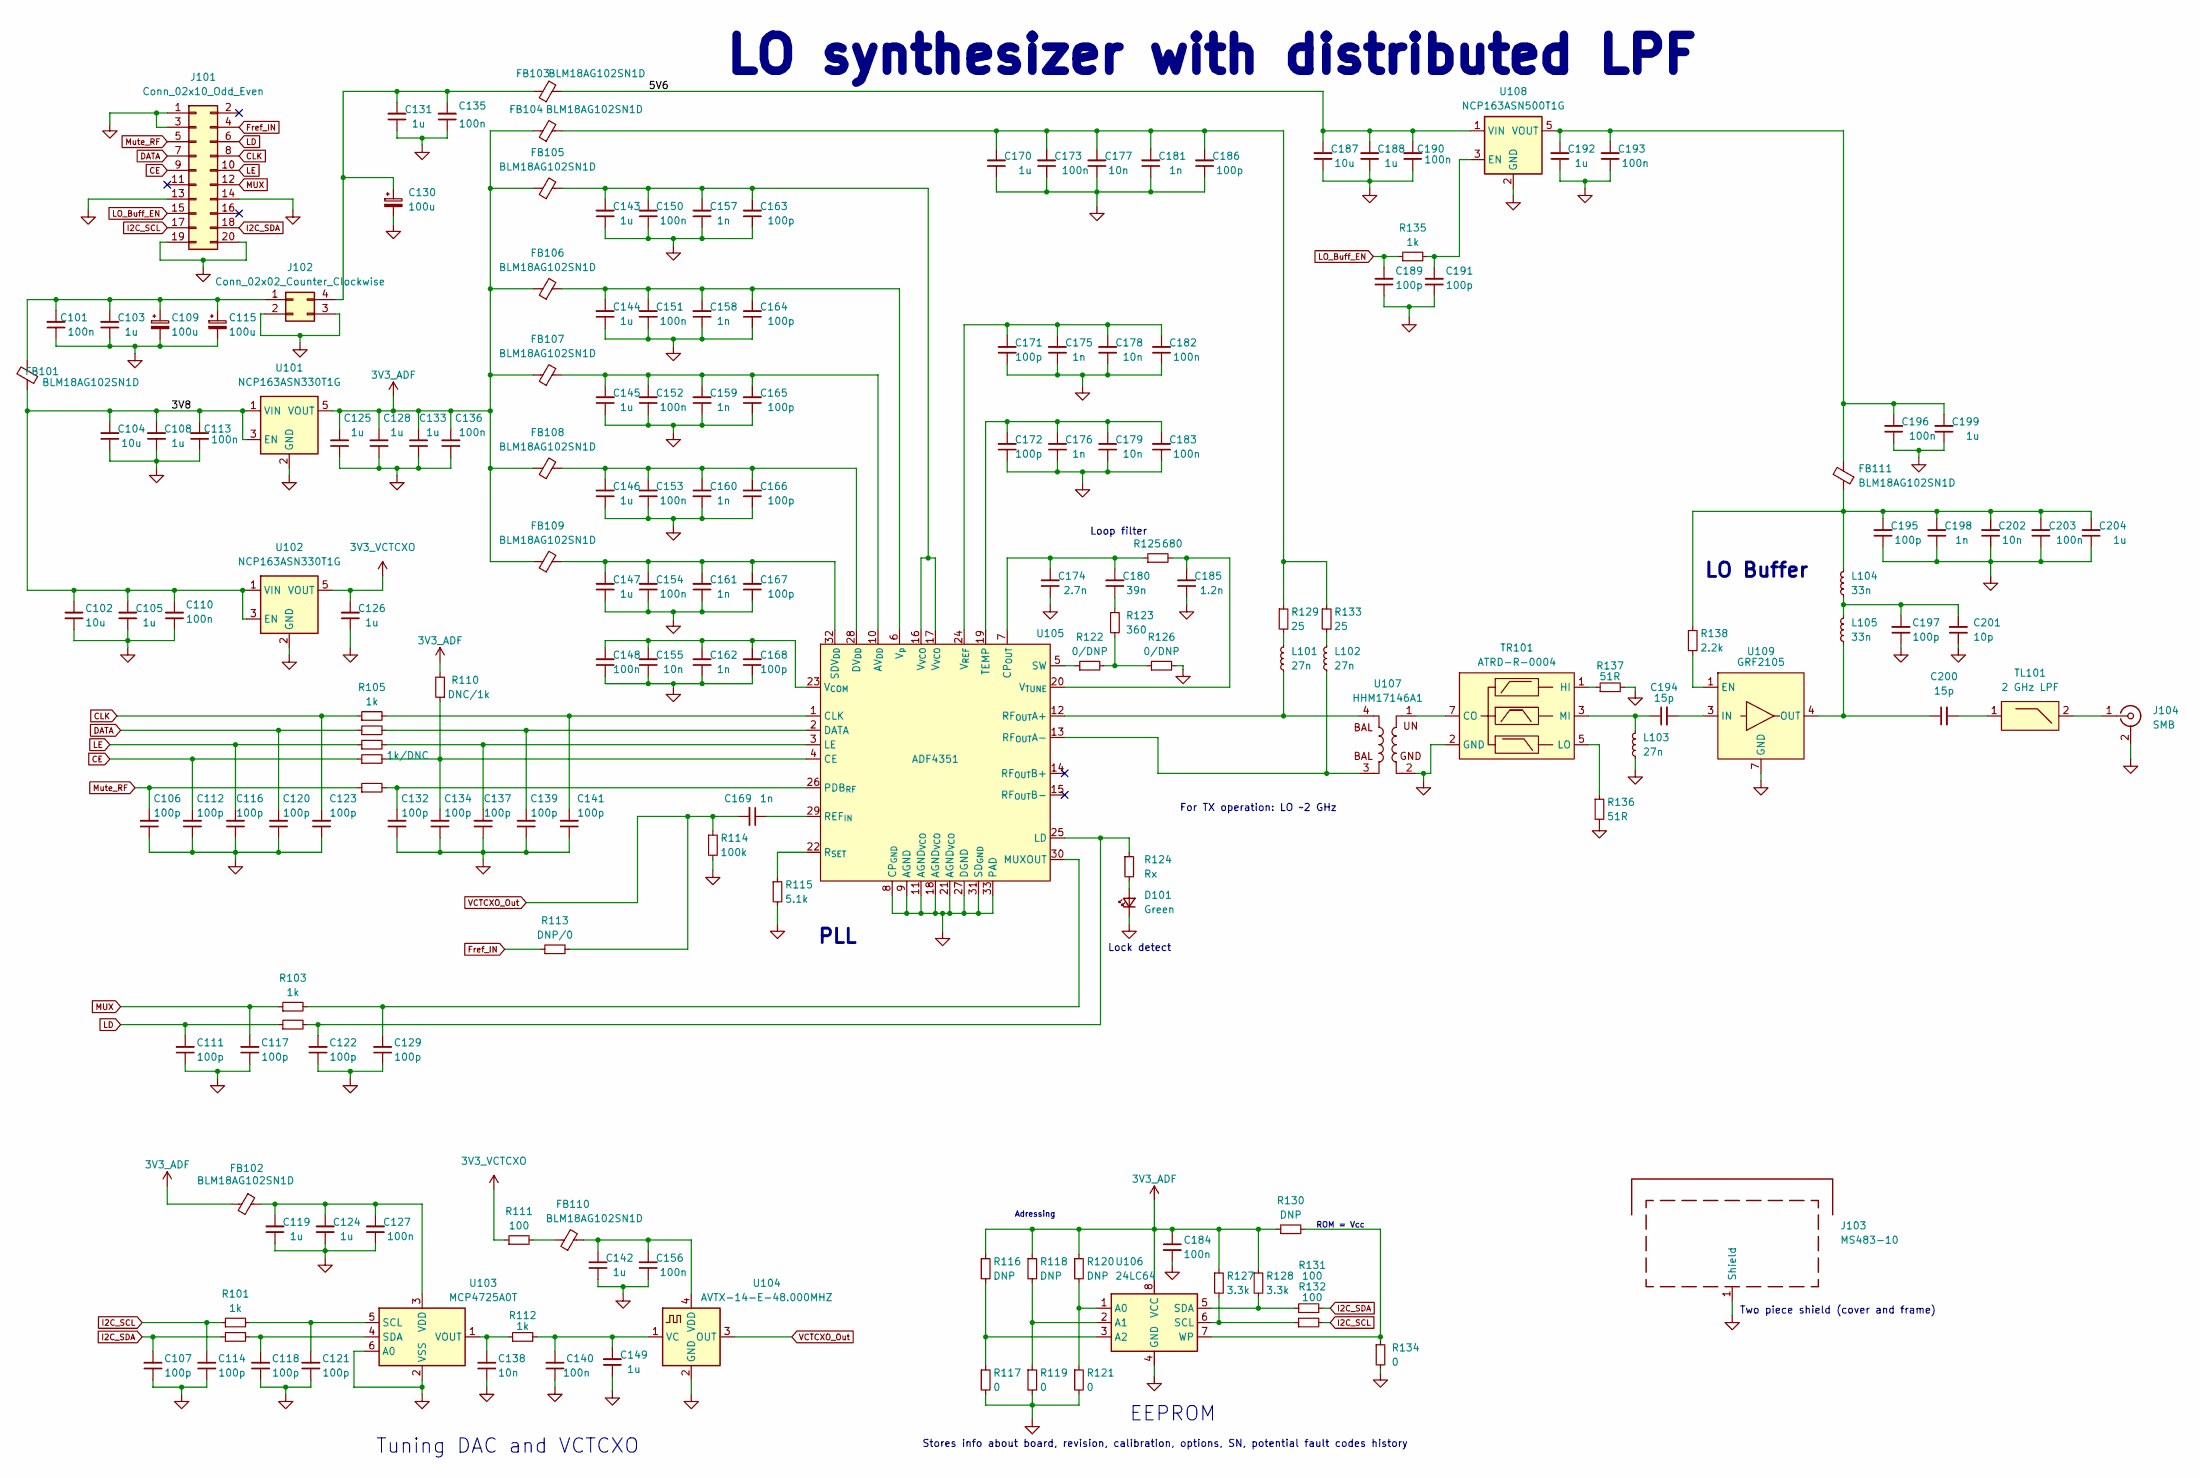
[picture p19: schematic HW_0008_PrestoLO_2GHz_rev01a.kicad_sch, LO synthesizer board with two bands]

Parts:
C101, C110, C113, C127, C136, C140, C148, C150, C151, C152, C153, C154, C156, C173, C182, C183, C184, C190, C193, C196, C203: 100n; C_0603_1608Metric_Pad1.08x0.95mm_HandSolder
C102, C104, C187: 10u; LED_0805_2012Metric
C103, C131, C188, C192, C199: 1u; C_0805_2012Metric_Pad1.18x1.45mm_HandSolder
C105, C108, C119, C124, C125, C126, C128, C133, C142, C143, C144, C145, C146, C147, C149, C170, C204: 1u; C_0603_1608Metric_Pad1.08x0.95mm_HandSolder
C106, C107, C111, C112, C114, C116, C117, C118, C120, C121, C122, C123, C129, C132, C134, C137, C139, C141, C163, C164, C165, C166, C167, C168, C171, C172, C186, C189, C191, C195, C197: 100p; C_0603_1608Metric_Pad1.08x0.95mm_HandSolder
C109, C115, C130: 100u; CP_Elec_6.3x5.8
C135: 100n; C_0805_2012Metric_Pad1.18x1.45mm_HandSolder
C138, C155, C177, C178, C179, C202: 10n; C_0603_1608Metric_Pad1.08x0.95mm_HandSolder
C157, C158, C159, C160, C161, C162, C169, C175, C176, C181, C198: 1n; C_0603_1608Metric_Pad1.08x0.95mm_HandSolder
C174: 2.7n; C_0603_1608Metric_Pad1.08x0.95mm_HandSolder
C180: 39n; C_0603_1608Metric_Pad1.08x0.95mm_HandSolder
C185: 1.2n; C_0603_1608Metric_Pad1.08x0.95mm_HandSolder
C194, C200: 15p; C_0603_1608Metric_Pad1.08x0.95mm_HandSolder
C201: 10p; C_0603_1608Metric_Pad1.08x0.95mm_HandSolder
D101: Green; D_0805_2012Metric_Pad1.15x1.40mm_HandSolder
FB101: BLM18AG102SN1D; L_0805_2012Metric_Pad1.15x1.40mm_HandSolder
FB102, FB104, FB105, FB106, FB107, FB108, FB109, FB110, FB111: BLM18AG102SN1D; L_0603_1608Metric_Pad1.05x0.95mm_HandSolder
FB103: BLM18AG102SN1D; L_0805_2012Metric_Pad1.05x1.20mm_HandSolder
J101: Conn_02x10_Odd_Even; PinHeader_2x10_P2.54mm_Vertical
J102: Conn_02x02_Counter_Clockwise; PinHeader_2x02_P2.54mm_Vertical
J103: MS483-10; MS4830-10
J104: SMB; SMB_Jack_Vertical
L101, L102, L103: 27n; L_0805_2012Metric_Pad1.05x1.20mm_HandSolder
L104, L105: 33n; L_0603_1608Metric_Pad1.05x0.95mm_HandSolder
R101, R102, R103, R104, R105, R106, R107, R109, R112, R135: 1k; R_0603_1608Metric_Pad0.98x0.95mm_HandSolder
R108: 1k/DNC; R_0603_1608Metric_Pad0.98x0.95mm_HandSolder
R110: DNC/1k; R_0603_1608Metric_Pad0.98x0.95mm_HandSolder
R111, R131, R132: 100; R_0603_1608Metric_Pad0.98x0.95mm_HandSolder
R113: DNP/0; R_0603_1608Metric_Pad0.98x0.95mm_HandSolder
R114: 100k; R_0603_1608Metric_Pad0.98x0.95mm_HandSolder
R115: 5.1k; R_0603_1608Metric_Pad0.98x0.95mm_HandSolder
R116, R118, R120: DNP; R_0805_2012Metric_Pad1.20x1.40mm_HandSolder
R117, R119, R121: 0; R_0805_2012Metric_Pad1.20x1.40mm_HandSolder
R122, R126: 0/DNP; R_0603_1608Metric_Pad0.98x0.95mm_HandSolder
R123: 360; R_0603_1608Metric_Pad0.98x0.95mm_HandSolder
R124: Rx; R_0603_1608Metric_Pad0.98x0.95mm_HandSolder
R125: 680; R_0603_1608Metric_Pad0.98x0.95mm_HandSolder
R127, R128: 3.3k; R_0603_1608Metric_Pad0.98x0.95mm_HandSolder
R129, R133: 25; R_0603_1608Metric_Pad0.98x0.95mm_HandSolder
R130: DNP; R_0603_1608Metric_Pad0.98x0.95mm_HandSolder
R134: 0; R_0603_1608Metric_Pad0.98x0.95mm_HandSolder
R136, R137: 51R; R_0402_1005Metric_Pad0.72x0.64mm_HandSolder
R138: 2.2k; R_0603_1608Metric_Pad0.98x0.95mm_HandSolder
TL101: 2 GHz LPF; Microstrip_2GHz_LPF
TR101: ATRD-R-0004; TPX252690MT-7029A
U101, U102: NCP163ASN330T1G; SOT-23-5
U103: MCP4725A0T; SOT-23-6
U104: AVTX-14-E-48.000MHZ; AbracomAVTX_14
U105: ADF4351; LFCSP-32-1EP_5x5mm_P0.5mm_EP3.5x3.5mm_ThermalVias
U106: 24LC64; SOIC-8_3.9x4.9mm_P1.27mm
U107: HHM17146A1
U108: NCP163ASN500T1G; SOT-23-5
U109: GRF2105; DFN-6-1EP_2x2mm_P0.5mm_EP0.6x1.37mm

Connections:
3V3_ADF: C125.2, C128.2, C133.2, C136.2, C184.1, FB102.2, FB104.1, FB105.1, FB106.1, FB107.1, FB108.1, FB109.1, R110.2, R116.1, R118.1, R120.1, R127.1, R128.1, R130.1, U101.5 (VOUT), U106.8 (VCC)
3V3_VCTCXO: C126.2, R111.1, U102.5 (VOUT)
/3V8: C102.2, C104.2, C105.2, C108.2, C110.2, C113.2, FB101.1, U101.1 (VIN), U101.3 (EN), U102.1 (VIN), U102.3 (EN)
/5V6: C187.2, C188.2, C190.2, FB103.2, U108.1 (VIN)
CE: C112.2, J101.9, R108.1
CLK: C123.2, J101.8, R105.1
DATA: C120.2, J101.7, R106.1
Fref_IN: J101.4, R113.1
GND: C101.1, C102.1, C103.1, C104.1, C105.1, C106.1, C107.1, C108.1, C109.2, C110.1, C111.1, C112.1, C113.1, C114.1, C115.2, C116.1, C117.1, C118.1, C119.1, C120.1, C121.1, C122.1, C123.1, C124.1, C125.1, C126.1, C127.1, C128.1, C129.1, C130.2, C131.1, C132.1, C133.1, C134.1, C135.1, C136.1, C137.1, C138.1, C139.1, C140.1, C141.1, C142.1, C143.1, C144.1, C145.1, C146.1, C147.1, C148.1, C149.1, C150.1, C151.1, C152.1, C153.1, C154.1, C155.1, C156.1, C157.1, C158.1, C159.1, C160.1, C161.1, C162.1, C163.1, C164.1, C165.1, C166.1, C167.1, C168.1, C170.1, C171.1, C172.1, C173.1, C174.1, C175.1, C176.1, C177.1, C178.1, C179.1, C181.1, C182.1, C183.1, C184.2, C185.1, C186.1, C187.1, C188.1, C189.1, C190.1, C191.1, C192.1, C193.1, C195.1, C196.1, C197.1, C198.1, C199.1, C201.1, C202.1, C203.1, C204.1, D101.1 (K), J101.1, J101.3, J101.13, J101.14, J101.19, J101.20, J102.2, J102.3, J103.1 (Shield), J104.2 (Ext), L103.1, R114.2, R115.2, R117.2, R119.2, R121.2, R126.2, R134.2, R136.2, R137.2, TR101.2 (GND), TR101.4 (GND), TR101.6 (GND), TR101.8 (GND), TR101.9 (GND), U101.2 (GND), U102.2 (GND), U103.2 (VSS), U103.6 (A0), U104.2 (GND), U105.8 (CP_{GND}), U105.9 (AGND), U105.11 (AGND_{VCO}), U105.18 (AGND_{VCO}), U105.21 (AGND_{VCO}), U105.27 (DGND), U105.31 (SD_{GND}), U105.33 (PAD), U106.4 (GND), U107.2, U107.5, U108.2 (GND), U109.2 (GND), U109.5 (GND), U109.6 (GND), U109.7 (GND)
I2C_SCL: C114.2, J101.17, R101.1, R132.2
I2C_SDA: C107.2, J101.18, R102.1, R131.2
LD: C111.2, J101.6, R104.1
LE: C116.2, J101.10, R107.1
LO_Buff_EN: C189.2, J101.15, R135.1
MUX: C117.2, J101.12, R103.1
Mute_RF: C106.2, J101.5, R109.1
unnamed: C143.2, C150.2, C157.2, C163.2, FB105.2, U105.16 (V_{VCO}), U105.17 (V_{VCO})
unnamed: C170.2, C173.2, C177.2, C181.2, C186.2, FB104.2, R129.1, R133.1
unnamed: C180.1, R123.1
unnamed: C195.2, C198.2, C202.2, C203.2, C204.2, FB111.1, L104.2, R138.1
unnamed: C197.2, C201.2, L104.1, L105.2
unnamed: C200.2, TL101.1
unnamed: D101.2 (A), R124.2
unnamed: FB110.1, R111.2
unnamed: C101.2, C103.2, C109.1, C115.1, FB101.2, J102.1
unnamed: C130.1, C131.2, C135.2, FB103.1, J102.4
unnamed: J104.1 (In), TL101.2
unnamed: L101.2, R129.2
unnamed: L102.2, R133.2
unnamed: R122.2, R123.2, R126.1
unnamed: TR101.7 (CO), U107.1
unnamed: R137.1, TR101.1 (HI)
unnamed: R136.1, TR101.5 (LO)
unnamed: C194.1, L103.2, TR101.3 (MI)
unnamed: C121.2, R101.2, U103.5 (SCL)
unnamed: C118.2, R102.2, U103.4 (SDA)
unnamed: C119.2, C124.2, C127.2, FB102.1, U103.3 (VDD)
unnamed: C138.2, R112.1, U103.1 (VOUT)
unnamed: C140.2, C149.2, R112.2, U104.1 (VC)
unnamed: C142.2, C156.2, FB110.2, U104.4 (VDD)
unnamed: C145.2, C152.2, C159.2, C165.2, FB107.2, U105.10 (AV_{DD})
unnamed: C134.2, R108.2, R110.1, U105.4 (CE)
unnamed: C141.2, R105.2, U105.1 (CLK)
unnamed: C174.2, C180.2, R125.1, U105.7 (CP_{OUT})
unnamed: C139.2, R106.2, U105.2 (DATA)
unnamed: C146.2, C153.2, C160.2, C166.2, FB108.2, U105.28 (DV_{DD})
unnamed: C122.2, R104.2, R124.1, U105.25 (LD)
unnamed: C137.2, R107.2, U105.3 (LE)
unnamed: C129.2, R103.2, U105.30 (MUXOUT)
unnamed: C132.2, R109.2, U105.26 (PDB_{RF})
unnamed: C169.1, U105.29 (REF_{IN})
unnamed: L101.1, U105.12 (RF_{OUT}A+), U107.4
unnamed: L102.1, U105.13 (RF_{OUT}A-), U107.3
unnamed: R115.1, U105.22 (R_{SET})
unnamed: C147.2, C154.2, C161.2, C167.2, FB109.2, U105.32 (SDV_{DD})
unnamed: R122.1, U105.5 (SW)
unnamed: C172.2, C176.2, C179.2, C183.2, U105.19 (TEMP)
unnamed: C148.2, C155.2, C162.2, C168.2, U105.23 (V_{COM})
unnamed: C171.2, C175.2, C178.2, C182.2, U105.24 (V_{REF})
unnamed: C185.2, R125.2, U105.20 (V_{TUNE})
unnamed: C144.2, C151.2, C158.2, C164.2, FB106.2, U105.6 (V_{p})
unnamed: R120.2, R121.1, U106.1 (A0)
unnamed: R118.2, R119.1, U106.2 (A1)
unnamed: R116.2, R117.1, U106.3 (A2)
unnamed: R127.2, R132.1, U106.6 (SCL)
unnamed: R128.2, R131.1, U106.5 (SDA)
unnamed: R130.2, R134.1, U106.7 (WP)
unnamed: C191.2, R135.2, U108.3 (EN)
unnamed: C192.2, C193.2, C196.2, C199.2, FB111.2, U108.5 (VOUT)
unnamed: R138.2, U109.1 (EN)
unnamed: C194.2, U109.3 (IN)
unnamed: C200.1, L105.1, U109.4 (OUT)
VCTCXO_Out: C169.2, R113.2, R114.1, U104.3 (OUT)

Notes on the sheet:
EEPROM
Two piece shield (cover and frame)
Adressing
Tuning DAC and VCTCXO
Lock detect
PLL
For TX operation: LO ~2 GHz
LO Buffer
Loop filter
LO synthesizer with distributed LPF
Stores info about board, revision, calibration, options, SN, potential fault codes history
ROM = Vcc

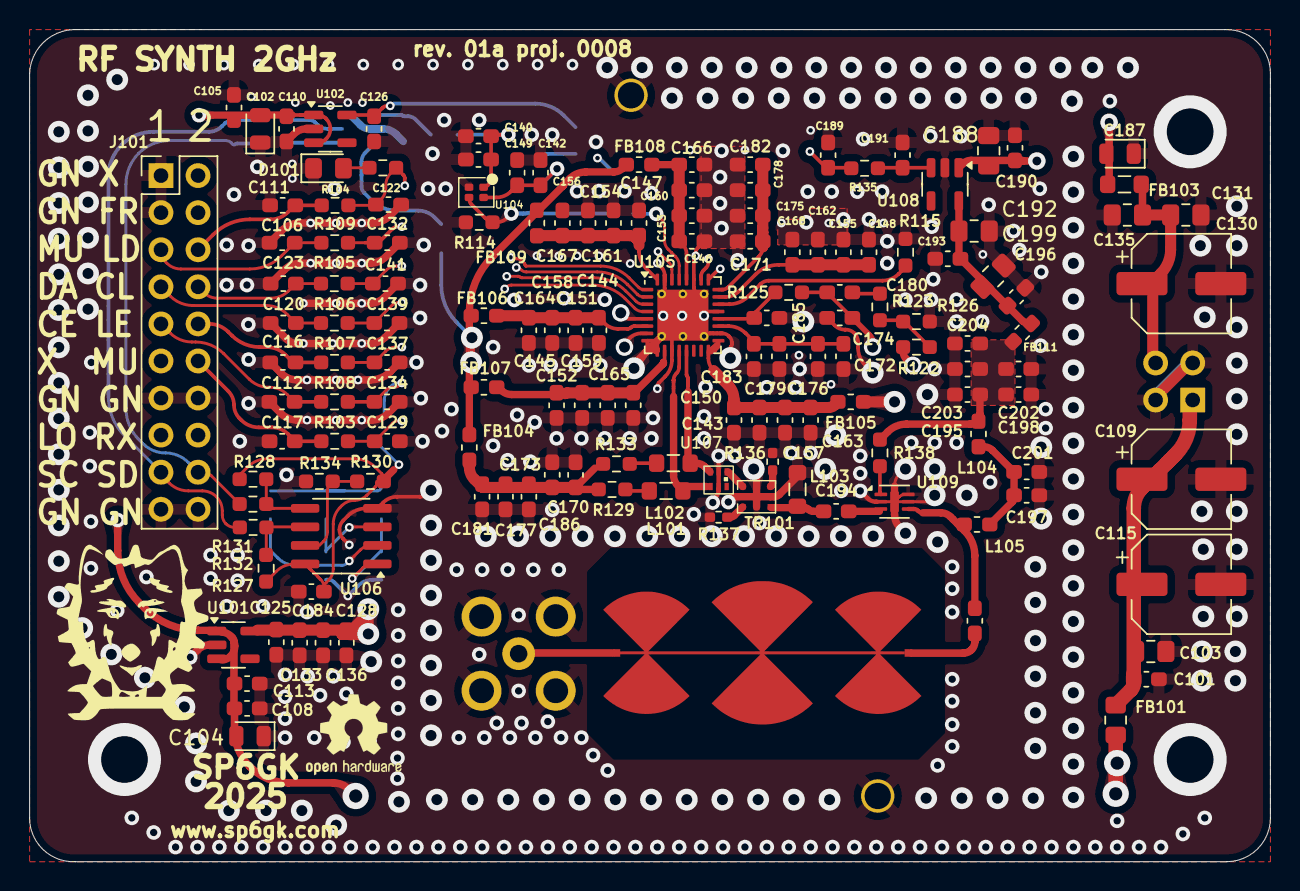
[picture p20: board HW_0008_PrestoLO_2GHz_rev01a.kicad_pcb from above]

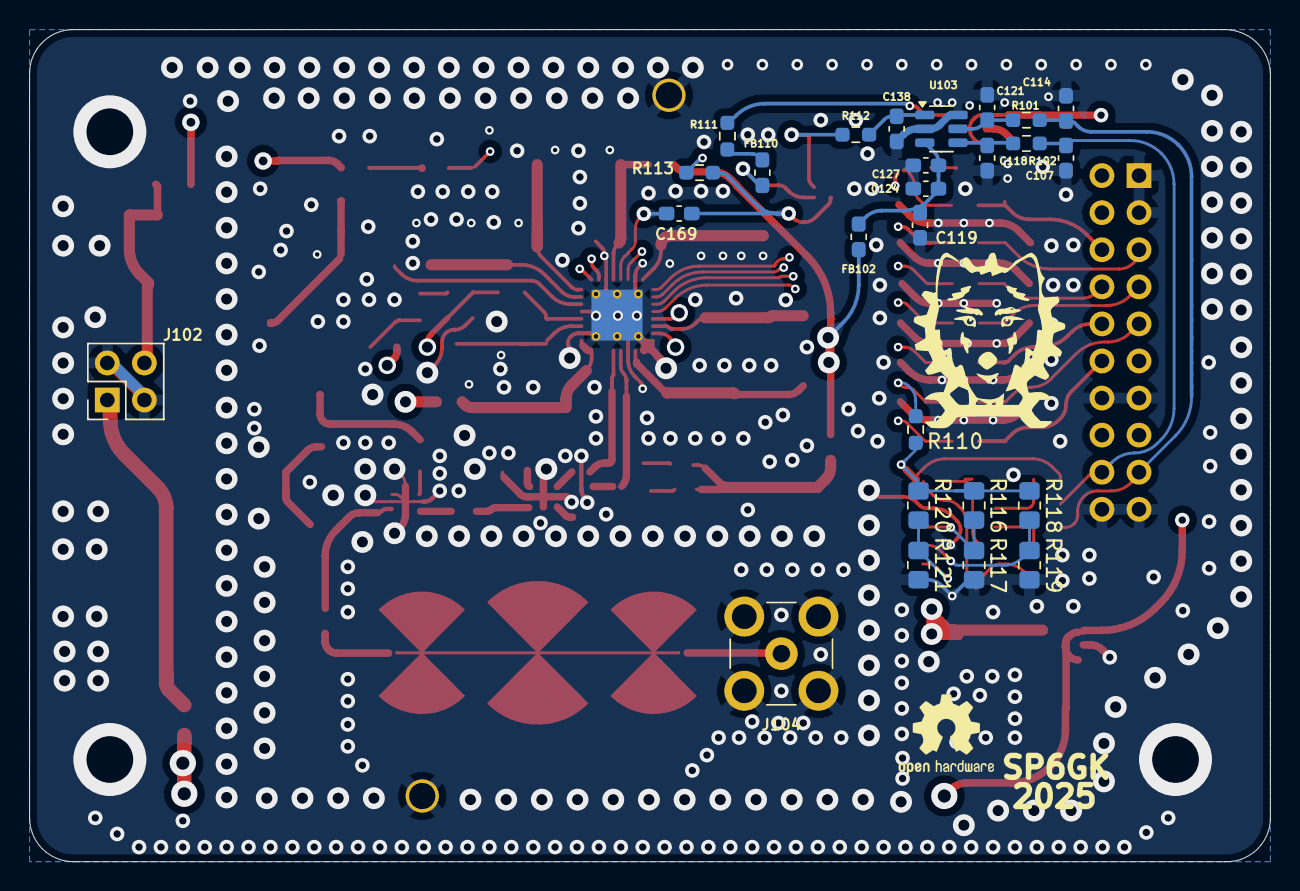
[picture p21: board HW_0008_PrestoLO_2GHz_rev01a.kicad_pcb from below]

Board: 4 copper layers, 85.0 x 57.0 mm, 174 parts (26 on the bottom side), 73 nets.

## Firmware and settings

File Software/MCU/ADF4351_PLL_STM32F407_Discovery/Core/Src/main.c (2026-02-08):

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
/* Includes ------------------------------------------------------------------*/
#include "main.h"

/* USER CODE BEGIN Includes */

#include "adf4351.h"
/* USER CODE END Includes */

//SPI_HandleTypeDef hspi1;

void SystemClock_Config(void);
static void MX_GPIO_Init(void);
static void MX_SPI1_Init(void);
/**
  * @brief  The application entry point.
  * @retval int
  */
int main(void)
{

  /* MCU Configuration--------------------------------------------------------*/

  /* Reset of all peripherals, Initializes the Flash interface and the Systick. */
  HAL_Init();

  /* USER CODE BEGIN Init */
  //Setup initial state for SPI IO
  	HAL_GPIO_WritePin(SPI1_CSn_GPIO_Port, SPI1_CSn_Pin, 1);
    HAL_GPIO_WritePin(SPI1_LD_GPIO_Port, SPI1_LD_Pin, 1);
    // set LED default states (turns them on)
    //HAL_GPIO_WritePin(LD3_GPIO_Port, LD3_Pin, 1);
  /* USER CODE END Init */

  /* Configure the system clock */
  SystemClock_Config();

  /* Initialize all configured peripherals */
  MX_GPIO_Init();
  MX_SPI1_Init();
  /* USER CODE BEGIN 2 */


  cmd_sm_init(); //Initializes PLL


  int64_t frequency = 100e6;
  int64_t current_frequency = 0;
  HAL_Delay(100);
  adf4350_out_altvoltage0_frequency(frequency);
 // adf4350_out_altvoltage0_powerdown(1);
  /* USER CODE END 2 */

  /* Infinite loop */
  /* USER CODE BEGIN WHILE */
  while (1)
  {

	 // adf4350_out_altvoltage0_frequency(frequency);
	  HAL_Delay(1000);
	  HAL_GPIO_TogglePin(GPIOD, LED_Debug_Pin);
    /* USER CODE END WHILE */

    /* USER CODE BEGIN 3 */
  }
  /* USER CODE END 3 */
}

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
/* USER CODE BEGIN 4 */

adf4350_init_param pll_config;

void cmd_sm_init() {
  // initialize pll_config structure
  pll_config.clkin = 48e6; //TODO change to 25?
  pll_config.channel_spacing = 100;
  pll_config.power_up_frequency = 400e6;
  pll_config.reference_div_factor = 1;
  pll_config.reference_doubler_enable = 0;
  pll_config.reference_div2_enable = 0;
  pll_config.phase_detector_polarity_positive_enable = 1;
  pll_config.lock_detect_precision_6ns_enable = 0; // 10 ns
  pll_config.lock_detect_function_integer_n_enable = 0; // Fractional pll
  pll_config.charge_pump_current = 7; //2.50
  pll_config.muxout_select = 6; // Digital Lock Detect Out
  pll_config.low_spur_mode_enable = 0; // higher noise, lower spurs.
  pll_config.cycle_slip_reduction_enable = 0;
  pll_config.charge_cancellation_enable = 0;
  pll_config.anti_backlash_3ns_enable = 0;
  pll_config.band_select_clock_mode_high_enable = 0; // low
  pll_config.clk_divider_12bit = 0;
  pll_config.clk_divider_mode = 0;
  pll_config.aux_output_enable = 0;
  pll_config.aux_output_fundamental_enable = 0;
  pll_config.mute_till_lock_enable = 1;
  pll_config.output_power = 0b11;
  pll_config.aux_output_power = 0b11;
  adf4350_out_altvoltage0_powerdown(0); // power down PLL
  adf4350_setup(pll_config);
}

/* USER CODE END 4 */
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


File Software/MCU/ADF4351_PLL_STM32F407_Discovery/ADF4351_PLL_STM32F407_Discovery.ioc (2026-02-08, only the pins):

Mcu.UserName=STM32F407VGTx
PA5.Signal=SPI1_SCK
PA6.GPIO_Label=SPI1_CSn
PA6.Signal=GPIO_Output
PA7.Signal=SPI1_MOSI
PC4.GPIO_Label=SPI1_LD
PC4.Signal=GPIO_Output
PD14.GPIO_Label=LED_Debug
PD14.Signal=GPIO_Output

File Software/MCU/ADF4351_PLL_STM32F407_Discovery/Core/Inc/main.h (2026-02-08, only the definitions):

#define SPI1_CSn_Pin GPIO_PIN_6
#define SPI1_CSn_GPIO_Port GPIOA
#define SPI1_LD_Pin GPIO_PIN_4
#define SPI1_LD_GPIO_Port GPIOC
#define LED_Debug_Pin GPIO_PIN_14
#define LED_Debug_GPIO_Port GPIOD

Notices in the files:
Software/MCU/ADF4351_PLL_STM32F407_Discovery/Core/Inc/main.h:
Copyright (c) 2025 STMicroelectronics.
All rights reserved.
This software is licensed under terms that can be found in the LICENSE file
